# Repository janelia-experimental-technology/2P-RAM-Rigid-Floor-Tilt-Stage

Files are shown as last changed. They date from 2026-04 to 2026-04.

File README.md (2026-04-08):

### 2P-RAM Rigid Floor Tilt Stage

Various custom components have been designed for use with the 2P-RAM, including head plates and a motorized head positioner tilt stage. The original tilt stage is a motorized positioner intended for use with an air-suspended ball treadmill, which can be somewhat complex and expensive. An alternative is a rigid floor for the test subject with a single degree of freedom for adjustment. The design is compatible with the head plates offered in another repo from the Janelia Experimental Technology (jET) GitHub org.

Opportunity: Free to make for Non-Profit Research by downloading the design here. See included hardware license.

Rights and designs available for Commercial License. Janelia makes no endorsements or guarantees of licensee products.

For inquiries, please contact innovation@janelia.hhmi.org and reference this repository.

To cite the designs, please use DOI: https://doi.org/10.25378/janelia.31963896

Supersedes Flintbox ID: 2018-024

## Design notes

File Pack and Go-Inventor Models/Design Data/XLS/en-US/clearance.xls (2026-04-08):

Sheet: Ansi Unified Screw Threads
I | Sort Order -1
Fastener Type | Size | Shaft Diameters |  |  | Head Dimensions
 |  | Close | Normal | Loose | Diameter | Depth/Angle | Head Type
Flat Head Machine Screw (82) | #0 | 0.0635 | 0.07 | 0.073 | 0.119 | 82 | 2
Flat Head Machine Screw (82) | #1 | 0.076 | 0.081 | 0.089 | 0.146 | 82 | 2
Flat Head Machine Screw (82) | #2 | 0.089 | 0.096 | 0.1065 | 0.172 | 82 | 2
Flat Head Machine Screw (82) | #3 | 0.104 | 0.11 | 0.12 | 0.199 | 82 | 2
Flat Head Machine Screw (82) | #4 | 0.116 | 0.1285 | 0.136 | 0.225 | 82 | 2
Flat Head Machine Screw (82) | #5 | 0.1285 | 0.136 | 0.154 | 0.252 | 82 | 2
Flat Head Machine Screw (82) | #6 | 0.144 | 0.1495 | 0.1695 | 0.279 | 82 | 2
Flat Head Machine Screw (82) | #8 | 0.1695 | 0.177 | 0.1935 | 0.332 | 82 | 2
Flat Head Machine Screw (82) | #10 | 0.196 | 0.201 | 0.221 | 0.385 | 82 | 2
Flat Head Machine Screw (82) | #12 | 0.221 | 0.228 | 0.246 | 0.438 | 82 | 2
Flat Head Machine Screw (82) | 1/4 | 0.257 | 0.266 | 0.2812 | 0.507 | 82 | 2
Flat Head Machine Screw (82) | 5/16 | 0.323 | 0.332 | 0.3437 | 0.635 | 82 | 2
Flat Head Machine Screw (82) | 3/8 | 0.386 | 0.397 | 0.4062 | 0.762 | 82 | 2
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

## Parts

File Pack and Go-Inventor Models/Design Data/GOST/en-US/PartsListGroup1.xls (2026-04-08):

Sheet: Лист 1
Инв. № подл |  |  |  | Подп. и дата | Взам. инв. № | Инв. № дубл. |  |  | Подп. и дата
Формат | Зона | Поз. | Обозначение |  |  |  | Наименование |  |  |  |  |  | Кол. на исполнение
 |  |  |  |  |  |  |  |  |  |  |  | Лит.
 |  |  |  |  |  |  |  |  |  |  |  | Код
 |  |  |  |  |  |  |  | Изм. | Лист | № докум | Подпись |  | Дата
 |  |  |  |  |  |  |  | Разраб.
 |  |  |  |  |  |  |  | Пров.
 |  |  |  |  |  |  |  | Н.контр
 |  |  |  |  |  |  |  | Утв.
 |  |  |  |  |  |  |  |  |  |  |  |  |  | Копировал

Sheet: Лист 2
Инв. № подл |  |  |  | Подп. и дата | Взам. инв. № | Инв. № дубл. |  |  | Подп. и дата
Формат | Зона | Поз. | Обозначение |  |  |  | Наименование |  |  |  |  | Кол. на исполнение
 |  |  |  |  |  |  |  | Изм. | Лист | № докум. | Подп. | Дата
 |  |  |  |  |  |  |  |  |  |  |  |  | Копировал
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

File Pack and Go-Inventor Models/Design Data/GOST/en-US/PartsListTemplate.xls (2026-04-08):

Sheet: Лист 1
 | Формат | Зона |  | Поз. |  | Обозначение |  |  |  | Наименование |  |  |  | Кол. | Приме-чание
Подп. и дата
Инв. № дубл.
Взам. инв. №
Подп. и дата
 | Изм. |  | Лист |  | № докум |  | Подпись | Дата
Инв. № подл | Разраб. |  |  |  |  |  |  |  |  |  | Литера |  | Лист |  |  | Листов
 | Пров.
 | Н.контр
 | Утв.
 |  |  |  |  |  |  |  |  | Копировал |  |  | Формат А4

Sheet: Лист 2
 | Формат | Зона |  | Поз. |  | Обозначение |  |  |  | Наименование |  | Кол. | Приме-чание
Подп. и дата
Инв. № дубл.
Взам. инв. №
Подп. и дата
Инв. № подл
 | Изм. |  | Лист |  | № докум. |  | Подп. |  | Дата
 |  |  |  |  |  |  |  | Копировал |  |  | Формат А4
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

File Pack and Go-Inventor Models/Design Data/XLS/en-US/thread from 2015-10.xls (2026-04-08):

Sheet: Inch Tapping Threads
I Q X | Inch Tapping Threads |  | Sort Order - 5 |  | External |  |  |  |  |  |  | Internal
 |  |  |  |  |  | Major Dia |  | Pitch Dia |  | Minor Dia |  |  | Minor Dia |  | Pitch Dia |  | Major Dia |  | Tap Drill
Size | Size Suffix | Thread Designation | Custom Thread Designation | TPI | Class | Max | Min | Max | Min | Max | Min | Class | Min | Max | Min | Max | Min | Max | Basic
0.0600 |  | 0-48 | 0-48 | 48 | 2B | 0.0600 | 0.0540 | 0.0480 | 0.0435 | 0.0360 | 0.0330
0.0730 |  | 1-42 | 1-42 | 42 | 2B | 0.0750 | 0.0690 | 0.0620 | 0.0575 | 0.0490 | 0.0460
0.0860 |  | 2-32 | 2-32 | 32 | 2B | 0.0880 | 0.0820 | 0.0760 | 0.0710 | 0.0640 | 0.0600
0.0990 |  | 3-28 | 3-28 | 28 | 2B | 0.1010 | 0.0950 | 0.0880 | 0.0830 | 0.0750 | 0.0710
0.1120 |  | 4-24 | 4-24 | 24 | 2B | 0.1140 | 0.1080 | 0.1000 | 0.0950 | 0.0860 | 0.0820
0.1250 |  | 5-20 | 5-20 | 20 | 2B | 0.1300 | 0.1230 | 0.1120 | 0.1065 | 0.0940 | 0.0900
0.1380 |  | 6-20 | 6-20 | 20 | 2B | 0.1390 | 0.1320 | 0.1215 | 0.1155 | 0.1040 | 0.0990
0.1510 |  | 7-19 | 7-19 | 19 | 2B | 0.1540 | 0.1470 | 0.1345 | 0.1280 | 0.1150 | 0.1090
0.1640 |  | 8-18 | 8-18 | 18 | 2B | 0.1660 | 0.1590 | 0.1440 | 0.1375 | 0.1220 | 0.1160
0.1900 |  | 10-16 | 10-16 | 16 | 2B | 0.1890 | 0.1820 | 0.1650 | 0.1585 | 0.1410 | 0.1350
0.2160 |  | 12-14 | 12-14 | 14 | 2B | 0.2150 | 0.2080 | 0.1895 | 0.1825 | 0.1640 | 0.1570
0.2420 |  | 14-14 | 14-14 | 14 | 2B | 0.2410 | 0.2340 | 0.2130 | 0.2060 | 0.1850 | 0.1780
0.2500 |  | 1/4-14 | 1/4-14 | 14 | 2B | 0.2460 | 0.2370 | 0.2190 | 0.2110 | 0.1920 | 0.1850
0.3125 |  | 5/16-12 | 5/16-12 | 12 | 2B | 0.3150 | 0.3060 | 0.2795 | 0.2710 | 0.2440 | 0.2360
0.3750 |  | 3/8-12 | 3/8-12 | 12 | 2B | 0.3800 | 0.3710 | 0.3445 | 0.3350 | 0.3090 | 0.2990
0.4375 |  | 7/16-10 | 7/16-10 | 10 | 2B | 0.4400 | 0.4290 | 0.3995 | 0.3890 | 0.3590 | 0.3490
0.5000 |  | 1/2-10 | 1/2-10 | 10 | 2B | 0.5040 | 0.4930 | 0.4635 | 0.4530 | 0.4230 | 0.4130

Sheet: Metric Forming Screw Threads
M P X | Metric Forming Screw Threads |  | Sort Order - 6 |  | External |  |  |  |  |  |  | Internal
 |  |  |  |  |  | Major Dia |  | Pitch Dia |  | Minor Dia |  |  | Minor Dia |  | Pitch Dia |  | Major Dia |  | Tap Drill
Size | Size Suffix | Thread Designation | Custom Thread Designation | Pitch | Class | Max | Min | Max | Min | Max | Min | Class | Min | Max | Min | Max | Min | Max | Basic
1.5 |  | 1.5x0.5 | 1.5x0.5 | 0.5 | 6g | 1.520 | 1.380 | 1.215 | 1.110 | 0.910 | 0.840
1.5 |  | ST1.5x0.5 | ST1.5x0.5 | 0.5 | 6g | 1.520 | 1.380 | 1.215 | 1.110 | 0.910 | 0.840
1.9 |  | 1.9x0.6 | 1.9x0.6 | 0.6 | 6g | 1.900 | 1.760 | 1.570 | 1.465 | 1.240 | 1.170
1.9 |  | ST1.9x0.6 | ST1.9x0.6 | 0.6 | 6g | 1.900 | 1.760 | 1.570 | 1.465 | 1.240 | 1.170
2.2 |  | 2.2x0.8 | 2.2x0.8 | 0.8 | 6g | 2.240 | 2.100 | 1.935 | 1.810 | 1.630 | 1.520
2.2 |  | ST2.2x0.8 | ST2.2x0.8 | 0.8 | 6g | 2.240 | 2.100 | 1.935 | 1.810 | 1.630 | 1.520
2.6 |  | 2.6x0.9 | 2.6x0.9 | 0.9 | 6g | 2.570 | 2.430 | 2.235 | 2.115 | 1.900 | 1.800
2.6 |  | ST2.6x0.9 | ST2.6x0.9 | 0.9 | 6g | 2.570 | 2.430 | 2.235 | 2.115 | 1.900 | 1.800
2.9 |  | 2.9x1 | 2.9x1 | 1 | 6g | 2.900 | 2.760 | 2.540 | 2.420 | 2.180 | 2.080
2.9 |  | 2.9x1.1 | 2.9x1.1 | 1.1 | 6g | 2.900 | 2.760 | 2.540 | 2.420 | 2.180 | 2.080
2.9 |  | ST2.9x1.1 | ST2.9x1.1 | 1.1 | 6g | 2.900 | 2.760 | 2.540 | 2.420 | 2.180 | 2.080
2.9 |  | 2.9x1.3 | 2.9x1.3 | 1.3 | 6g | 2.900 | 2.720 | 2.540 | 2.355 | 1.890 | 1.700
2.9 |  | 2.9x1.4 | 2.9x1.4 | 1.4 | 6g | 2.900 | 2.720 | 2.340 | 2.175 | 1.780 | 1.630
3.3 |  | 3.3x1.3 | 3.3x1.3 | 1.3 | 6g | 3.300 | 3.120 | 2.795 | 2.665 | 2.290 | 2.210
3.3 |  | ST3.3x1.3 | ST3.3x1.3 | 1.3 | 6g | 3.300 | 3.120 | 2.795 | 2.665 | 2.290 | 2.210
3.5 |  | 3.5x1.3 | 3.5x1.3 | 1.3 | 6g | 3.530 | 3.350 | 3.085 | 2.930 | 2.640 | 2.510
3.5 |  | ST3.5x1.3 | ST3.5x1.3 | 1.3 | 6g | 3.530 | 3.350 | 3.085 | 2.930 | 2.640 | 2.510
3.5 |  | 3.5x1.6 | 3.5x1.6 | 1.6 | 6g | 3.530 | 3.350 | 2.920 | 2.755 | 2.310 | 2.160
3.5 |  | 3.5x3.2 | 3.5x3.2 | 3.2 | 6g | 3.530 | 3.310 | 2.800 | 2.600 | 2.070 | 1.890
3.9 |  | 3.9x1.3 | 3.9x1.3 | 1.3 | 6g | 3.910 | 3.730 | 3.415 | 3.250 | 2.920 | 2.770
3.9 |  | ST3.9x1.3 | ST3.9x1.3 | 1.3 | 6g | 3.910 | 3.730 | 3.415 | 3.250 | 2.920 | 2.770
3.9 |  | 3.9x1.6 | 3.9x1.6 | 1.6 | 6g | 3.910 | 3.730 | 3.300 | 3.135 | 2.690 | 2.540
3.9 |  | 3.9x3.2 | 3.9x3.2 | 3.2 | 6g | 3.910 | 3.690 | 3.180 | 2.980 | 2.450 | 2.270
4.2 |  | 4.2x1.4 | 4.2x1.4 | 1.4 | 6g | 4.220 | 4.040 | 3.660 | 3.495 | 3.100 | 2.950
4.2 |  | ST4.2x1.4 | ST4.2x1.4 | 1.4 | 6g | 4.220 | 4.040 | 3.660 | 3.495 | 3.100 | 2.950
4.2 |  | 4.2x1.6 | 4.2x1.6 | 1.6 | 6g | 4.220 | 4.040 | 3.610 | 3.445 | 3.000 | 2.850
4.2 |  | 4.2x3.2 | 4.2x3.2 | 3.2 | 6g | 4.220 | 4.000 | 3.380 | 3.180 | 2.540 | 2.360
4.8 |  | 4.8x1.6 | 4.8x1.6 | 1.6 | 6g | 4.800 | 4.620 | 4.190 | 4.025 | 3.580 | 3.430
4.8 |  | ST4.8x1.6 | ST4.8x1.6 | 1.6 | 6g | 4.800 | 4.620 | 4.190 | 4.025 | 3.580 | 3.430
4.8 |  | 4.8x1.8 | 4.8x1.8 | 1.8 | 6g | 4.800 | 4.620 | 4.065 | 3.885 | 3.330 | 3.150
4.8 |  | 4.8x3.2 | 4.8x3.2 | 3.2 | 6g | 4.800 | 4.580 | 3.960 | 3.760 | 3.120 | 2.940
5.5 |  | 5.5x1.8 | 5.5x1.8 | 1.8 | 6g | 5.460 | 5.280 | 4.815 | 4.635 | 4.170 | 3.990
5.5 |  | ST5.5x1.8 | ST5.5x1.8 | 1.8 | 6g | 5.460 | 5.280 | 4.815 | 4.635 | 4.170 | 3.990
6.3 |  | 6.3x1.8 | 6.3x1.8 | 1.8 | 6g | 6.250 | 6.030 | 5.565 | 5.365 | 4.880 | 4.700
6.3 |  | ST6.3x1.8 | ST6.3x1.8 | 1.8 | 6g | 6.250 | 6.030 | 5.565 | 5.365 | 4.880 | 4.700
8.0 |  | 8x2.1 | 8x2.1 | 2.1 | 6g | 8.000 | 7.780 | 7.100 | 6.885 | 6.200 | 5.990
8.0 |  | ST8x2.1 | ST8x2.1 | 2.1 | 6g | 8.000 | 7.780 | 7.100 | 6.885 | 6.200 | 5.990
9.5 |  | 9.5x2.1 | 9.5x2.1 | 2.1 | 6g | 9.650 | 9.430 | 8.750 | 8.510 | 7.850 | 7.590
9.5 |  | ST9.5x2.1 | ST9.5x2.1 | 2.1 | 6g | 9.650 | 9.430 | 8.750 | 8.510 | 7.850 | 7.590

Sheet: ISO Pipe Threads
M Q | ISO Pipe Threads |  | Sort Order - 9 |  | External |  |  |  |  |  |  | Internal
 |  |  |  |  |  | Major Dia |  | Pitch Dia |  | Minor Dia |  |  | Minor Dia |  | Pitch Dia |  | Major Dia |  | Tap Drill | Thread Depth | Thread Runouts
Size | Size Suffix | Thread Designation | Custom Thread Designation | TPI | Class | Max | Min | Max | Min | Max | Min | Class | Min | Max | Min | Max | Min | Max | Basic
7.723 |  | G7.723x0.907 | G 1/16 | 28 | A | 7.723 | 7.509 | 7.142 | 7.035 | 6.561 |  |  | 6.561 | 6.834 | 7.142 | 7.249 | 7.723 |  | 1.5875 | 15.446 | 4.5000
7.723 |  | G7.723x0.907 | G 1/16 | 28 | B | 7.723 | 7.509 | 7.142 | 6.928 | 6.561
9.728 |  | G9.728x0.907 | G 1/8 | 28 | A | 9.728 | 9.514 | 9.147 | 9.040 | 8.566 |  |  | 8.566 | 8.848 | 9.147 | 9.254 | 9.728 |  | 3.1750 | 19.456 | 4.5000
9.728 |  | G9.728x0.907 | G 1/8 | 28 | B | 9.728 | 9.514 | 9.147 | 8.933 | 8.566
13.157 |  | G13.157x1.337 | G 1/4 | 19 | A | 13.157 | 12.907 | 12.301 | 12.176 | 11.445 |  |  | 11.445 | 11.89 | 12.301 | 12.426 | 13.157 |  | 6.3500 | 26.314 | 6.5000
13.157 |  | G13.157x1.337 | G 1/4 | 19 | B | 13.157 | 12.907 | 12.301 | 12.051 | 11.445
16.662 |  | G16.662x1.337 | G 3/8 | 19 | A | 16.662 | 16.412 | 15.806 | 15.681 | 14.950 |  |  | 14.95 | 15.395 | 15.806 | 15.931 | 16.662 |  | 9.5250 | 33.324 | 6.5000
16.662 |  | G16.662x1.337 | G 3/8 | 19 | B | 16.662 | 16.412 | 15.806 | 15.556 | 14.950
20.955 |  | G20.955x1.814 | G 1/2 | 14 | A | 20.955 | 20.671 | 19.793 | 19.651 | 18.631 |  |  | 18.631 | 19.172 | 19.793 | 19.935 | 20.955 |  | 12.7000 | 41.910 | 8.5000
20.955 |  | G20.955x1.814 | G 1/2 | 14 | B | 20.955 | 20.671 | 19.793 | 19.509 | 18.631
22.911 |  | G22.911x1.814 | G 5/8 | 14 | A | 22.911 | 22.627 | 21.749 | 21.607 | 20.587 |  |  | 20.587 | 21.128 | 21.749 | 21.891 | 22.911 |  |  | 45.822 | 8.5000
22.911 |  | G22.911x1.814 | G 5/8 | 14 | B | 22.911 | 22.627 | 21.749 | 21.465 | 20.587
26.441 |  | G26.441x1.814 | G 3/4 | 14 | A | 26.441 | 26.157 | 25.279 | 25.137 | 24.117 |  |  | 24.117 | 24.658 | 25.279 | 25.421 | 26.441 |  | 15.8750 | 52.882 | 8.5000
26.441 |  | G26.441x1.814 | G 3/4 | 14 | B | 26.441 | 26.157 | 25.279 | 24.995 | 24.117
30.201 |  | G30.201x1.814 | G 7/8 | 14 | A | 30.201 | 29.917 | 29.039 | 28.897 | 27.877 |  |  | 27.877 | 28.418 | 29.039 | 29.181 | 30.201 |  | 22.2250 | 60.402 | 8.5000
30.201 |  | G30.201x1.814 | G 7/8 | 14 | B | 30.201 | 29.917 | 29.039 | 28.755 | 27.877
33.249 |  | G33.249x2.309 | G 1 | 11 | A | 33.249 | 32.889 | 31.770 | 31.590 | 30.291 |  |  | 30.291 | 30.931 | 31.77 | 31.95 | 33.249 |  | 25.4000 | 66.498 | 10.0000
33.249 |  | G33.249x2.309 | G 1 | 11 | B | 33.249 | 32.889 | 31.770 | 31.410 | 30.291
37.897 |  | G37.897x2.309 | G 1 1/8 | 11 | A | 37.897 | 37.537 | 36.418 | 36.238 | 34.939 |  |  | 34.939 | 35.579 | 36.418 | 36.598 | 37.897 |  | 28.5750 | 75.794 | 10.0000
37.897 |  | G37.897x2.309 | G 1 1/8 | 11 | B | 37.897 | 37.537 | 36.418 | 36.058 | 34.939
41.910 |  | G41.91x2.309 | G 1 1/4 | 11 | A | 41.910 | 41.550 | 40.431 | 40.251 | 38.952 |  |  | 38.952 | 39.592 | 40.431 | 40.611 | 41.910 |  | 31.7500 | 83.820 | 10.0000
41.910 |  | G41.91x2.309 | G 1 1/4 | 11 | B | 41.910 | 41.550 | 40.431 | 40.071 | 38.952
47.803 |  | G47.803x2.309 | G 1 1/2 | 11 | A | 47.803 | 47.443 | 46.324 | 46.144 | 44.845 |  |  | 44.845 | 45.485 | 46.324 | 46.504 | 47.803 |  | 38.1000 | 95.606 | 10.0000
47.803 |  | G47.803x2.309 | G 1 1/2 | 11 | B | 47.803 | 47.443 | 46.324 | 45.964 | 44.845
53.746 |  | G53.746x2.309 | G 1 3/4 | 11 | A | 53.746 | 53.386 | 52.267 | 52.087 | 50.788 |  |  | 50.788 | 51.428 | 52.267 | 52.447 | 53.746 |  | 44.4500 | 107.492 | 10.0000
53.746 |  | G53.746x2.309 | G 1 3/4 | 11 | B | 53.746 | 53.386 | 52.267 | 51.907 | 50.788
59.614 |  | G59.614x2.309 | G 2 | 11 | A | 59.614 | 59.254 | 58.135 | 57.955 | 56.656 |  |  | 56.656 | 57.296 | 58.135 | 58.315 | 59.614 |  | 50.8000 | 119.228 | 10.0000
59.614 |  | G59.614x2.309 | G 2 | 11 | B | 59.614 | 59.254 | 58.135 | 57.775 | 56.656
65.710 |  | G65.71x2.309 | G 2 1/4 | 11 | A | 65.710 | 65.276 | 64.231 | 64.014 | 62.752 |  |  | 62.752 | 63.392 | 64.231 | 64.448 | 65.710 |  | 57.1500 | 131.420 | 10.0000
65.710 |  | G65.71x2.309 | G 2 1/4 | 11 | B | 65.710 | 65.276 | 64.231 | 63.797 | 62.752
75.184 |  | G75.184x2.309 | G 2 1/2 | 11 | A | 75.184 | 74.750 | 73.705 | 73.488 | 72.226 |  |  | 72.226 | 72.866 | 73.705 | 73.922 | 75.184 |  |  | 150.368 | 10.0000
75.184 |  | G75.184x2.309 | G 2 1/2 | 11 | B | 75.184 | 74.750 | 73.705 | 73.271 | 72.226
81.534 |  | G81.534x2.309 | G 2 3/4 | 11 | A | 81.534 | 81.100 | 80.055 | 79.838 | 78.576 |  |  | 78.576 | 79.216 | 80.055 | 80.272 | 81.534 |  | 69.8500 | 163.068 | 10.0000
81.534 |  | G81.534x2.309 | G 2 3/4 | 11 | B | 81.534 | 81.100 | 80.055 | 79.621 | 78.576
87.884 |  | G87.884x2.309 | G 3 | 11 | A | 87.884 | 87.450 | 86.405 | 86.188 | 84.926 |  |  | 84.926 | 85.566 | 86.405 | 86.622 | 87.884 |  | 76.2000 | 175.768 | 10.0000
87.884 |  | G87.884x2.309 | G 3 | 11 | B | 87.884 | 87.450 | 86.405 | 85.971 | 84.926
100.330 |  | G100.33x2.309 | G 3 1/2 | 11 | A | 100.330 | 99.896 | 98.851 | 98.634 | 97.372 |  |  | 97.372 | 98.012 | 98.851 | 99.068 | 100.330 |  | 88.9000 | 200.660 | 10.0000
100.330 |  | G100.33x2.309 | G 3 1/2 | 11 | B | 100.330 | 99.896 | 98.851 | 98.417 | 97.372
113.030 |  | G113.03x2.309 | G 4 | 11 | A | 113.030 | 112.596 | 111.551 | 111.334 | 110.072 |  |  | 110.072 | 110.712 | 111.551 | 111.768 | 113.030 |  | 101.6000 | 226.060 | 10.0000
113.030 |  | G113.03x2.309 | G 4 | 11 | B | 113.030 | 112.596 | 111.551 | 111.117 | 110.072
125.730 |  | G125.73x2.309 | G 4 1/2 | 11 | A | 125.730 | 125.296 | 124.251 | 124.034 | 122.772 |  |  | 122.772 | 123.412 | 124.251 | 124.468 | 125.730 |  | 114.3000 | 251.460 | 10.0000
125.730 |  | G125.73x2.309 | G 4 1/2 | 11 | B | 125.730 | 125.296 | 124.251 | 123.817 | 122.772
138.430 |  | G138.43x2.309 | G 5 | 11 | A | 138.430 | 137.996 | 136.951 | 136.734 | 135.472 |  |  | 135.472 | 136.112 | 136.951 | 137.168 | 138.430 |  | 127.0000 | 276.860 | 10.0000
138.430 |  | G138.43x2.309 | G 5 | 11 | B | 138.430 | 137.996 | 136.951 | 136.517 | 135.472
151.130 |  | G151.13x2.309 | G 5 1/2 | 11 | A | 151.130 | 150.696 | 149.651 | 149.434 | 148.172 |  |  | 148.172 | 148.812 | 149.651 | 149.868 | 151.130 |  | 139.7000 | 302.260 | 10.0000
151.130 |  | G151.13x2.309 | G 5 1/2 | 11 | B | 151.130 | 150.696 | 149.651 | 149.217 | 148.172
163.830 |  | G163.83x2.309 | G 6 | 11 | A | 163.830 | 163.396 | 162.351 | 162.134 | 160.872 |  |  | 160.872 | 161.512 | 162.351 | 162.568 | 163.830 |  | 152.4000 | 327.660 | 10.0000
163.830 |  | G163.83x2.309 | G 6 | 11 | B | 163.830 | 163.396 | 162.351 | 161.917 | 160.872

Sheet: JIS Pipe Threads
M Q | JIS Pipe Threads |  | Sort Order -12 |  | External |  |  |  |  |  |  | Internal
 |  |  |  |  |  | Major Dia |  | Pitch Dia |  | Minor Dia |  |  | Minor Dia |  | Pitch Dia |  | Major Dia |  | Tap Drill | Thread Depth | Thread Runouts
Size | Size Suffix | Thread Designation | Custom Thread Designation | TPI | Class | Max | Min | Max | Min | Max | Min | Class | Min | Max | Min | Max | Min | Max | Basic |  | Basic
7.723 |  | G7.723x0.907 | G 1/16 | 28 | A | 7.723 | 7.509 | 7.142 | 7.035 | 6.561 |  |  | 6.561 | 6.834 | 7.142 | 7.249 | 7.723 |  | 1.5875 | 15.446 | 4.5000
7.723 |  | G7.723x0.907 | G 1/16 | 28 | B | 7.723 | 7.509 | 7.142 | 6.928 | 6.561
9.728 |  | G9.728x0.907 | G 1/8 | 28 | A | 9.728 | 9.514 | 9.147 | 9.040 | 8.566 |  |  | 8.566 | 8.848 | 9.147 | 9.254 | 9.728 |  | 3.1750 | 19.456 | 4.5000
9.728 |  | G9.728x0.907 | G 1/8 | 28 | B | 9.728 | 9.514 | 9.147 | 8.933 | 8.566
13.157 |  | G13.157x1.337 | G 1/4 | 19 | A | 13.157 | 12.907 | 12.301 | 12.176 | 11.445 |  |  | 11.445 | 11.89 | 12.301 | 12.426 | 13.157 |  | 6.3500 | 26.314 | 6.5000
13.157 |  | G13.157x1.337 | G 1/4 | 19 | B | 13.157 | 12.907 | 12.301 | 12.051 | 11.445
16.662 |  | G16.662x1.337 | G 3/8 | 19 | A | 16.662 | 16.412 | 15.806 | 15.681 | 14.950 |  |  | 14.95 | 15.395 | 15.806 | 15.931 | 16.662 |  | 9.5250 | 33.324 | 6.5000
16.662 |  | G16.662x1.337 | G 3/8 | 19 | B | 16.662 | 16.412 | 15.806 | 15.556 | 14.950
20.955 |  | G20.955x1.814 | G 1/2 | 14 | A | 20.955 | 20.671 | 19.793 | 19.651 | 18.631 |  |  | 18.631 | 19.172 | 19.793 | 19.935 | 20.955 |  | 12.7000 | 41.910 | 8.5000
20.955 |  | G20.955x1.814 | G 1/2 | 14 | B | 20.955 | 20.671 | 19.793 | 19.509 | 18.631
22.911 |  | G22.911x1.814 | G 5/8 | 14 | A | 22.911 | 22.627 | 21.749 | 21.607 | 20.587 |  |  | 20.587 | 21.128 | 21.749 | 21.891 | 22.911 |  |  | 45.822 | 8.5000
22.911 |  | G22.911x1.814 | G 5/8 | 14 | B | 22.911 | 22.627 | 21.749 | 21.465 | 20.587
26.441 |  | G26.441x1.814 | G 3/4 | 14 | A | 26.441 | 26.157 | 25.279 | 25.137 | 24.117 |  |  | 24.117 | 24.658 | 25.279 | 25.421 | 26.441 |  | 15.8750 | 52.882 | 8.5000
26.441 |  | G26.441x1.814 | G 3/4 | 14 | B | 26.441 | 26.157 | 25.279 | 24.995 | 24.117
30.201 |  | G30.201x1.814 | G 7/8 | 14 | A | 30.201 | 29.917 | 29.039 | 28.897 | 27.877 |  |  | 27.877 | 28.418 | 29.039 | 29.181 | 30.201 |  | 22.2250 | 60.402 | 8.8000
30.201 |  | G30.201x1.814 | G 7/8 | 14 | B | 30.201 | 29.917 | 29.039 | 28.755 | 27.877
33.249 |  | G33.249x2.309 | G 1 | 11 | A | 33.249 | 32.889 | 31.770 | 31.590 | 30.291 |  |  | 30.291 | 30.931 | 31.77 | 31.95 | 33.249 |  | 25.4000 | 66.498 | 10.0000
33.249 |  | G33.249x2.309 | G 1 | 11 | B | 33.249 | 32.889 | 31.770 | 31.410 | 30.291
37.897 |  | G37.897x2.309 | G 1 1/8 | 11 | A | 37.897 | 37.537 | 36.418 | 36.238 | 34.939 |  |  | 34.939 | 35.579 | 36.418 | 36.598 | 37.897 |  | 28.5750 | 75.794 | 10.0000
37.897 |  | G37.897x2.309 | G 1 1/8 | 11 | B | 37.897 | 37.537 | 36.418 | 36.058 | 34.939
41.910 |  | G41.91x2.309 | G 1 1/4 | 11 | A | 41.910 | 41.550 | 40.431 | 40.251 | 38.952 |  |  | 38.952 | 39.592 | 40.431 | 40.611 | 41.910 |  | 31.7500 | 83.820 | 10.0000
41.910 |  | G41.91x2.309 | G 1 1/4 | 11 | B | 41.910 | 41.550 | 40.431 | 40.071 | 38.952
47.803 |  | G47.803x2.309 | G 1 1/2 | 11 | A | 47.803 | 47.443 | 46.324 | 46.144 | 44.845 |  |  | 44.845 | 45.485 | 46.324 | 46.504 | 47.803 |  | 38.1000 | 95.606 | 10.0000
47.803 |  | G47.803x2.309 | G 1 1/2 | 11 | B | 47.803 | 47.443 | 46.324 | 45.964 | 44.845
53.746 |  | G53.746x2.309 | G 1 3/4 | 11 | A | 53.746 | 53.386 | 52.267 | 52.087 | 50.788 |  |  | 50.788 | 51.428 | 52.267 | 52.447 | 53.746 |  | 44.4500 | 107.492 | 10.0000
53.746 |  | G53.746x2.309 | G 1 3/4 | 11 | B | 53.746 | 53.386 | 52.267 | 51.907 | 50.788
59.614 |  | G59.614x2.309 | G 2 | 11 | A | 59.614 | 59.254 | 58.135 | 57.955 | 56.656 |  |  | 56.656 | 57.296 | 58.135 | 58.315 | 59.614 |  | 50.8000 | 119.228 | 10.0000
59.614 |  | G59.614x2.309 | G 2 | 11 | B | 59.614 | 59.254 | 58.135 | 57.775 | 56.656
65.710 |  | G65.71x2.309 | G 2 1/4 | 11 | A | 65.710 | 65.276 | 64.231 | 64.014 | 62.752 |  |  | 62.752 | 63.392 | 64.231 | 64.448 | 65.710 |  | 57.1500 | 131.420 | 10.0000
65.710 |  | G65.71x2.309 | G 2 1/4 | 11 | B | 65.710 | 65.276 | 64.231 | 63.797 | 62.752
75.184 |  | G75.184x2.309 | G 2 1/2 | 11 | A | 75.184 | 74.750 | 73.705 | 73.488 | 72.226 |  |  | 72.226 | 72.866 | 73.705 | 73.922 | 75.184 |  |  | 150.368 | 10.0000
75.184 |  | G75.184x2.309 | G 2 1/2 | 11 | B | 75.184 | 74.750 | 73.705 | 73.271 | 72.226
81.534 |  | G81.534x2.309 | G 2 3/4 | 11 | A | 81.534 | 81.100 | 80.055 | 79.838 | 78.576 |  |  | 78.576 | 79.216 | 80.055 | 80.272 | 81.534 |  | 69.8500 | 163.068 | 10.0000
81.534 |  | G81.534x2.309 | G 2 3/4 | 11 | B | 81.534 | 81.100 | 80.055 | 79.621 | 78.576
87.884 |  | G87.884x2.309 | G 3 | 11 | A | 87.884 | 87.450 | 86.405 | 86.188 | 84.926 |  |  | 84.926 | 85.566 | 86.405 | 86.622 | 87.884 |  | 76.2000 | 175.768 | 10.0000
87.884 |  | G87.884x2.309 | G 3 | 11 | B | 87.884 | 87.450 | 86.405 | 85.971 | 84.926
100.330 |  | G100.33x2.309 | G 3 1/2 | 11 | A | 100.330 | 99.896 | 98.851 | 98.634 | 97.372 |  |  | 97.372 | 98.012 | 98.851 | 99.068 | 100.330 |  | 88.9000 | 200.660 | 10.0000
100.330 |  | G100.33x2.309 | G 3 1/2 | 11 | B | 100.330 | 99.896 | 98.851 | 98.417 | 97.372
113.030 |  | G113.03x2.309 | G 4 | 11 | A | 113.030 | 112.596 | 111.551 | 111.334 | 110.072 |  |  | 110.072 | 110.712 | 111.551 | 111.768 | 113.030 |  | 101.6000 | 226.060 | 10.0000
113.030 |  | G113.03x2.309 | G 4 | 11 | B | 113.030 | 112.596 | 111.551 | 111.117 | 110.072
125.730 |  | G125.73x2.309 | G 4 1/2 | 11 | A | 125.730 | 125.296 | 124.251 | 124.034 | 122.772 |  |  | 122.772 | 123.412 | 124.251 | 124.468 | 125.730 |  | 114.3000 | 251.460 | 10.0000
125.730 |  | G125.73x2.309 | G 4 1/2 | 11 | B | 125.730 | 125.296 | 124.251 | 123.817 | 122.772
138.430 |  | G138.43x2.309 | G 5 | 11 | A | 138.430 | 137.996 | 136.951 | 136.734 | 135.472 |  |  | 135.472 | 136.112 | 136.951 | 137.168 | 138.430 |  | 127.0000 | 276.860 | 10.0000
138.430 |  | G138.43x2.309 | G 5 | 11 | B | 138.430 | 137.996 | 136.951 | 136.517 | 135.472
151.130 |  | G151.13x2.309 | G 5 1/2 | 11 | A | 151.130 | 150.696 | 149.651 | 149.434 | 148.172 |  |  | 148.172 | 148.812 | 149.651 | 149.868 | 151.130 |  | 139.7000 | 302.260 | 10.0000
151.130 |  | G151.13x2.309 | G 5 1/2 | 11 | B | 151.130 | 150.696 | 149.651 | 149.217 | 148.172
163.830 |  | G163.83x2.309 | G 6 | 11 | A | 163.830 | 163.396 | 162.351 | 162.134 | 160.872 |  |  | 160.872 | 161.512 | 162.351 | 162.568 | 163.830 |  | 152.4000 | 327.660 | 10.0000
163.830 |  | G163.83x2.309 | G 6 | 11 | B | 163.830 | 163.396 | 162.351 | 161.917 | 160.872

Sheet: DIN Pipe Threads
M Q | DIN Pipe Threads |  | Sort Order - 18 |  | External |  |  |  |  |  |  | Internal
 |  |  |  |  |  | Major Dia |  | Pitch Dia |  | Minor Dia |  |  | Minor Dia |  | Pitch Dia |  | Major Dia |  | Tap Drill | Thread Depth | Thread Runouts
Size | Size Suffix | Thread Designation | Custom Thread Designation | TPI | Class | Max | Min | Max | Min | Max | Min | Class | Min | Max | Min | Max | Min | Max | Basic
7.723 |  | G7.723x0.907 | G 1/16 | 28 | A | 7.723 | 7.509 | 7.142 | 7.035 | 6.561 |  |  | 6.561 | 6.834 | 7.142 | 7.249 | 7.723 |  | 1.5875 | 15.446 | 4.5000
7.723 |  | G7.723x0.907 | G 1/16 | 28 | B | 7.723 | 7.509 | 7.142 | 6.928 | 6.561
9.728 |  | G9.728x0.907 | G 1/8 | 28 | A | 9.728 | 9.514 | 9.147 | 9.040 | 8.566 |  |  | 8.566 | 8.848 | 9.147 | 9.254 | 9.728 |  | 3.1750 | 19.456 | 4.5000
9.728 |  | G9.728x0.907 | G 1/8 | 28 | B | 9.728 | 9.514 | 9.147 | 8.933 | 8.566
13.157 |  | G13.157x1.337 | G 1/4 | 19 | A | 13.157 | 12.907 | 12.301 | 12.176 | 11.445 |  |  | 11.445 | 11.89 | 12.301 | 12.426 | 13.157 |  | 6.3500 | 26.314 | 6.5000
13.157 |  | G13.157x1.337 | G 1/4 | 19 | B | 13.157 | 12.907 | 12.301 | 12.051 | 11.445
16.662 |  | G16.662x1.337 | G 3/8 | 19 | A | 16.662 | 16.412 | 15.806 | 15.681 | 14.950 |  |  | 14.95 | 15.395 | 15.806 | 15.931 | 16.662 |  | 9.5250 | 33.324 | 6.5000
16.662 |  | G16.662x1.337 | G 3/8 | 19 | B | 16.662 | 16.412 | 15.806 | 15.556 | 14.950
20.955 |  | G20.955x1.814 | G 1/2 | 14 | A | 20.955 | 20.671 | 19.793 | 19.651 | 18.631 |  |  | 18.631 | 19.172 | 19.793 | 19.935 | 20.955 |  | 12.7000 | 41.910 | 8.5000
20.955 |  | G20.955x1.814 | G 1/2 | 14 | B | 20.955 | 20.671 | 19.793 | 19.509 | 18.631
22.911 |  | G22.911x1.814 | G 5/8 | 14 | A | 22.911 | 22.627 | 21.749 | 21.607 | 20.587 |  |  | 20.587 | 21.128 | 21.749 | 21.891 | 22.911 |  |  | 45.822 | 8.5000
22.911 |  | G22.911x1.814 | G 5/8 | 14 | B | 22.911 | 22.627 | 21.749 | 21.465 | 20.587
26.441 |  | G26.441x1.814 | G 3/4 | 14 | A | 26.441 | 26.157 | 25.279 | 25.137 | 24.117 |  |  | 24.117 | 24.658 | 25.279 | 25.421 | 26.441 |  | 15.8750 | 52.882 | 8.5000
26.441 |  | G26.441x1.814 | G 3/4 | 14 | B | 26.441 | 26.157 | 25.279 | 24.995 | 24.117
30.201 |  | G30.201x1.814 | G 7/8 | 14 | A | 30.201 | 29.917 | 29.039 | 28.897 | 27.877 |  |  | 27.877 | 28.418 | 29.039 | 29.181 | 30.201 |  | 22.2250 | 60.402 | 8.5000
30.201 |  | G30.201x1.814 | G 7/8 | 14 | B | 30.201 | 29.917 | 29.039 | 28.755 | 27.877
33.249 |  | G33.249x2.309 | G 1 | 11 | A | 33.249 | 32.889 | 31.770 | 31.590 | 30.291 |  |  | 30.291 | 30.931 | 31.77 | 31.95 | 33.249 |  | 25.4000 | 66.498 | 10.5000
33.249 |  | G33.249x2.309 | G 1 | 11 | B | 33.249 | 32.889 | 31.770 | 31.410 | 30.291
37.897 |  | G37.897x2.309 | G 1 1/8 | 11 | A | 37.897 | 37.537 | 36.418 | 36.238 | 34.939 |  |  | 34.939 | 35.579 | 36.418 | 36.598 | 37.897 |  | 28.5750 | 75.794 | 10.5000
37.897 |  | G37.897x2.309 | G 1 1/8 | 11 | B | 37.897 | 37.537 | 36.418 | 36.058 | 34.939
41.910 |  | G41.91x2.309 | G 1 1/4 | 11 | A | 41.910 | 41.550 | 40.431 | 40.251 | 38.952 |  |  | 38.952 | 39.592 | 40.431 | 40.611 | 41.910 |  | 31.7500 | 83.820 | 10.5000
41.910 |  | G41.91x2.309 | G 1 1/4 | 11 | B | 41.910 | 41.550 | 40.431 | 40.071 | 38.952
47.803 |  | G47.803x2.309 | G 1 1/2 | 11 | A | 47.803 | 47.443 | 46.324 | 46.144 | 44.845 |  |  | 44.845 | 45.485 | 46.324 | 46.504 | 47.803 |  | 38.1000 | 95.606 | 10.5000
47.803 |  | G47.803x2.309 | G 1 1/2 | 11 | B | 47.803 | 47.443 | 46.324 | 45.964 | 44.845
53.746 |  | G53.746x2.309 | G 1 3/4 | 11 | A | 53.746 | 53.386 | 52.267 | 52.087 | 50.788 |  |  | 50.788 | 51.428 | 52.267 | 52.447 | 53.746 |  | 44.4500 | 107.492 | 10.5000
53.746 |  | G53.746x2.309 | G 1 3/4 | 11 | B | 53.746 | 53.386 | 52.267 | 51.907 | 50.788
59.614 |  | G59.614x2.309 | G 2 | 11 | A | 59.614 | 59.254 | 58.135 | 57.955 | 56.656 |  |  | 56.656 | 57.296 | 58.135 | 58.315 | 59.614 |  | 50.8000 | 119.228 | 10.5000
59.614 |  | G59.614x2.309 | G 2 | 11 | B | 59.614 | 59.254 | 58.135 | 57.775 | 56.656
65.710 |  | G65.71x2.309 | G 2 1/4 | 11 | A | 65.710 | 65.276 | 64.231 | 64.014 | 62.752 |  |  | 62.752 | 63.392 | 64.231 | 64.448 | 65.710 |  | 57.1500 | 131.420 | 10.5000
65.710 |  | G65.71x2.309 | G 2 1/4 | 11 | B | 65.710 | 65.276 | 64.231 | 63.797 | 62.752
75.184 |  | G75.184x2.309 | G 2 1/2 | 11 | A | 75.184 | 74.750 | 73.705 | 73.488 | 72.226 |  |  | 72.226 | 72.866 | 73.705 | 73.922 | 75.184 |  |  | 150.368 | 10.5000
75.184 |  | G75.184x2.309 | G 2 1/2 | 11 | B | 75.184 | 74.750 | 73.705 | 73.271 | 72.226
81.534 |  | G81.534x2.309 | G 2 3/4 | 11 | A | 81.534 | 81.100 | 80.055 | 79.838 | 78.576 |  |  | 78.576 | 79.216 | 80.055 | 80.272 | 81.534 |  | 69.8500 | 163.068 | 10.5000
81.534 |  | G81.534x2.309 | G 2 3/4 | 11 | B | 81.534 | 81.100 | 80.055 | 79.621 | 78.576
87.884 |  | G87.884x2.309 | G 3 | 11 | A | 87.884 | 87.450 | 86.405 | 86.188 | 84.926 |  |  | 84.926 | 85.566 | 86.405 | 86.622 | 87.884 |  | 76.2000 | 175.768 | 10.5000
87.884 |  | G87.884x2.309 | G 3 | 11 | B | 87.884 | 87.450 | 86.405 | 85.971 | 84.926
100.330 |  | G100.33x2.309 | G 3 1/2 | 11 | A | 100.330 | 99.896 | 98.851 | 98.634 | 97.372 |  |  | 97.372 | 98.012 | 98.851 | 99.068 | 100.330 |  | 88.9000 | 200.660 | 10.5000
100.330 |  | G100.33x2.309 | G 3 1/2 | 11 | B | 100.330 | 99.896 | 98.851 | 98.417 | 97.372
113.030 |  | G113.03x2.309 | G 4 | 11 | A | 113.030 | 112.596 | 111.551 | 111.334 | 110.072 |  |  | 110.072 | 110.712 | 111.551 | 111.768 | 113.030 |  | 101.6000 | 226.060 | 10.5000
113.030 |  | G113.03x2.309 | G 4 | 11 | B | 113.030 | 112.596 | 111.551 | 111.117 | 110.072
125.730 |  | G125.73x2.309 | G 4 1/2 | 11 | A | 125.730 | 125.296 | 124.251 | 124.034 | 122.772 |  |  | 122.772 | 123.412 | 124.251 | 124.468 | 125.730 |  | 114.3000 | 251.460 | 10.5000
125.730 |  | G125.73x2.309 | G 4 1/2 | 11 | B | 125.730 | 125.296 | 124.251 | 123.817 | 122.772
138.430 |  | G138.43x2.309 | G 5 | 11 | A | 138.430 | 137.996 | 136.951 | 136.734 | 135.472 |  |  | 135.472 | 136.112 | 136.951 | 137.168 | 138.430 |  | 127.0000 | 276.860 | 10.5000
138.430 |  | G138.43x2.309 | G 5 | 11 | B | 138.430 | 137.996 | 136.951 | 136.517 | 135.472
151.130 |  | G151.13x2.309 | G 5 1/2 | 11 | A | 151.130 | 150.696 | 149.651 | 149.434 | 148.172 |  |  | 148.172 | 148.812 | 149.651 | 149.868 | 151.130 |  | 139.7000 | 302.260 | 10.5000
151.130 |  | G151.13x2.309 | G 5 1/2 | 11 | B | 151.130 | 150.696 | 149.651 | 149.217 | 148.172
163.830 |  | G163.83x2.309 | G 6 | 11 | A | 163.830 | 163.396 | 162.351 | 162.134 | 160.872 |  |  | 160.872 | 161.512 | 162.351 | 162.568 | 163.830 |  | 152.4000 | 327.660 | 10.5000
163.830 |  | G163.83x2.309 | G 6 | 11 | B | 163.830 | 163.396 | 162.351 | 161.917 | 160.872

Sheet: BSP Pipe Threads
M Q | BSP Pipe Threads |  | Sort Order - 19 |  | External |  |  |  |  |  |  | Internal
 |  |  |  |  |  | Major Dia |  | Pitch Dia |  | Minor Dia |  |  | Minor Dia |  | Pitch Dia |  | Major Dia |  | Tap Drill | Thread Depth | Thread Runouts
Size | Size Suffix | Thread Designation | Custom Thread Designation | TPI | Class | Max | Min | Max | Min | Max | Min | Class | Min | Max | Min | Max | Min | Max | Basic |  | Basic
1/16 |  | G 1/16-28 | G 1/16-28 | 28 | A | 7.723 | 7.509 | 7.142 | 7.035 | 6.561 |  |  | 6.561 | 6.834 | 7.142 | 7.249 | 7.723 |  | 6.6000 | 15.4460 | 4.5000
1/16 |  | G 1/16-28 | G 1/16-28 | 28 | B | 7.723 | 7.509 | 7.142 | 7.035 | 6.561
1/8 |  | G 1/8-28 | G 1/8-28 | 28 | A | 9.728 | 9.514 | 9.147 | 9.040 | 8.566 |  |  | 8.566 | 8.848 | 9.147 | 9.254 | 9.728 |  | 8.7300 | 19.4560 | 4.5000
1/8 |  | G 1/8-28 | G 1/8-28 | 28 | B | 9.728 | 9.514 | 9.147 | 9.040 | 8.566
1/4 |  | G 1/4-19 | G 1/4-19 | 19 | A | 13.157 | 12.907 | 12.301 | 12.176 | 11.445 |  |  | 11.445 | 11.89 | 12.301 | 12.426 | 13.157 |  | 11.8000 | 26.3140 | 6.5000
1/4 |  | G 1/4-19 | G 1/4-19 | 19 | B | 13.157 | 12.907 | 12.301 | 12.176 | 11.445
3/8 |  | G 3/8-19 | G 3/8-19 | 19 | A | 16.662 | 16.412 | 15.806 | 15.681 | 14.950 |  |  | 14.95 | 15.395 | 15.806 | 15.931 | 16.662 |  | 15.2500 | 33.3240 | 6.5000
3/8 |  | G 3/8-19 | G 3/8-19 | 19 | B | 16.662 | 16.412 | 15.806 | 15.681 | 14.950
1/2 |  | G 1/2-14 | G 1/2-14 | 14 | A | 20.955 | 20.671 | 19.793 | 19.651 | 18.631 |  |  | 18.631 | 19.172 | 19.793 | 19.935 | 20.955 |  | 19.0500 | 41.9100 | 8.5000
1/2 |  | G 1/2-14 | G 1/2-14 | 14 | B | 20.955 | 20.671 | 19.793 | 19.651 | 18.631
5/8 |  | G 5/8-14 | G 5/8-14 | 14 | A | 22.911 | 22.627 | 21.749 | 21.607 | 20.587 |  |  | 20.587 | 21.128 | 21.749 | 21.891 | 22.911 |  | 21.0000 | 45.8220 | 8.5000
5/8 |  | G 5/8-14 | G 5/8-14 | 14 | B | 22.911 | 22.627 | 21.749 | 21.607 | 20.587
3/4 |  | G 3/4-14 | G 3/4-14 | 14 | A | 26.441 | 26.157 | 25.279 | 25.137 | 24.117 |  |  | 24.117 | 24.658 | 25.279 | 25.421 | 26.441 |  | 24.5000 | 52.8820 | 8.5000
3/4 |  | G 3/4-14 | G 3/4-14 | 14 | B | 26.441 | 26.157 | 25.279 | 25.137 | 24.117
7/8 |  | G 7/8-14 | G 7/8-14 | 14 | A | 30.201 | 29.917 | 29.039 | 28.897 | 27.877 |  |  | 27.877 | 28.418 | 29.039 | 29.181 | 30.201 |  | 28.2500 | 60.4020 | 8.5000
7/8 |  | G 7/8-14 | G 7/8-14 | 14 | B | 30.201 | 29.917 | 29.039 | 28.897 | 27.877
1 |  | G 1-11 | G 1-11 | 11 | A | 33.249 | 32.889 | 31.770 | 31.590 | 30.291 |  |  | 30.291 | 30.931 | 31.77 | 31.95 | 33.249 |  | 30.7500 | 66.4980 | 10.0000
1 |  | G 1-11 | G 1-11 | 11 | B | 33.249 | 32.889 | 31.770 | 31.590 | 30.291
1 1/4 |  | G 1 1/4-11 | G 1 1/4-11 | 11 | A | 41.910 | 41.550 | 40.431 | 40.251 | 38.952 |  |  | 38.952 | 39.592 | 40.431 | 40.611 | 41.910 |  | 39.5000 | 83.8200 | 10.0000
1 1/4 |  | G 1 1/4-11 | G 1 1/4-11 | 11 | B | 41.910 | 41.550 | 40.431 | 40.251 | 38.952
1 1/2 |  | G 1 1/2-11 | G 1 1/2-11 | 11 | A | 47.803 | 47.443 | 46.324 | 46.144 | 44.845 |  |  | 44.845 | 45.485 | 46.324 | 46.504 | 47.803 |  | 45.5000 | 95.6060 | 10.0000
1 1/2 |  | G 1 1/2-11 | G 1 1/2-11 | 11 | B | 47.803 | 47.443 | 46.324 | 46.144 | 44.845
1 3/4 |  | G 1 3/4-11 | G 1 3/4-11 | 11 | A | 53.746 | 53.386 | 52.267 | 52.087 | 50.788 |  |  | 50.788 | 51.428 | 52.267 | 52.447 | 53.746 |  | 51.0000 | 107.4920 | 10.0000
1 3/4 |  | G 1 3/4-11 | G 1 3/4-11 | 11 | B | 53.746 | 53.386 | 52.267 | 52.087 | 50.788
2 |  | G 2-11 | G 2-11 | 11 | A | 59.614 | 59.254 | 58.135 | 57.955 | 56.656 |  |  | 56.656 | 57.296 | 58.135 | 58.315 | 59.614 |  | 57.0000 | 119.2280 | 10.0000
2 |  | G 2-11 | G 2-11 | 11 | B | 59.614 | 59.254 | 58.135 | 57.955 | 56.656
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

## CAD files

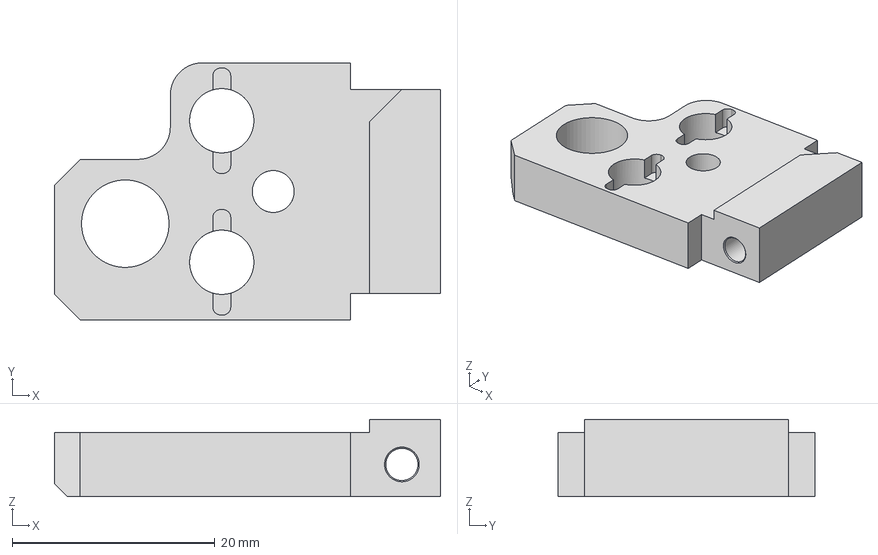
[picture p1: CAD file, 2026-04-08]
Part Drawings and Models/J005822 ANGLE ADJ UPPER Rev -.stp
38.1 x 25.4 x 7.62 mm

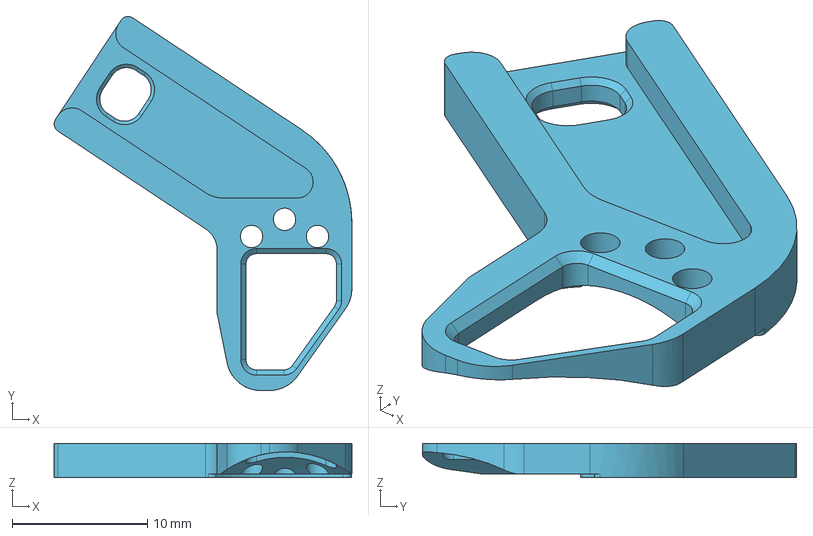
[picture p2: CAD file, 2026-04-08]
Part Drawings and Models/J005483 MBS INLINE D TAB Rev A.stp
22.0 x 27.6 x 2.54 mm

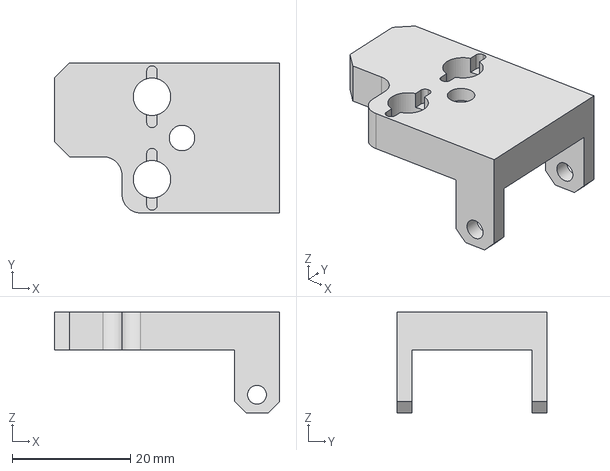
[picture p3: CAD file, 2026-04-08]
Part Drawings and Models/J005823 ANGLE ADJ LOWER Rev -.stp
38.1 x 25.4 x 17.0 mm

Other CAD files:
Pack and Go-Inventor Models/Templates/Other Default Autodesk Templates/English/am_ansi.dwg
Pack and Go-Inventor Models/Templates/Other Default Autodesk Templates/Metric/DIN.dwg
Pack and Go-Inventor Models/Templates/Standard.dwg
Pack and Go-Inventor Models/Templates/Other Default Autodesk Templates/English/ANSI (in).dwg
Pack and Go-Inventor Models/Templates/Other Default Autodesk Templates/Metric/JIS.dwg
Pack and Go-Inventor Models/Templates/Other Default Autodesk Templates/Metric/am_gb.dwg
Pack and Go-Inventor Models/Templates/Other Default Autodesk Templates/Metric/ISO.dwg
Pack and Go-Inventor Models/Templates/Other Default Autodesk Templates/Metric/am_jis.dwg
Pack and Go-Inventor Models/Templates/Other Default Autodesk Templates/Metric/BSI.dwg
Pack and Go-Inventor Models/Templates/Other Default Autodesk Templates/Metric/am_iso.dwg
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

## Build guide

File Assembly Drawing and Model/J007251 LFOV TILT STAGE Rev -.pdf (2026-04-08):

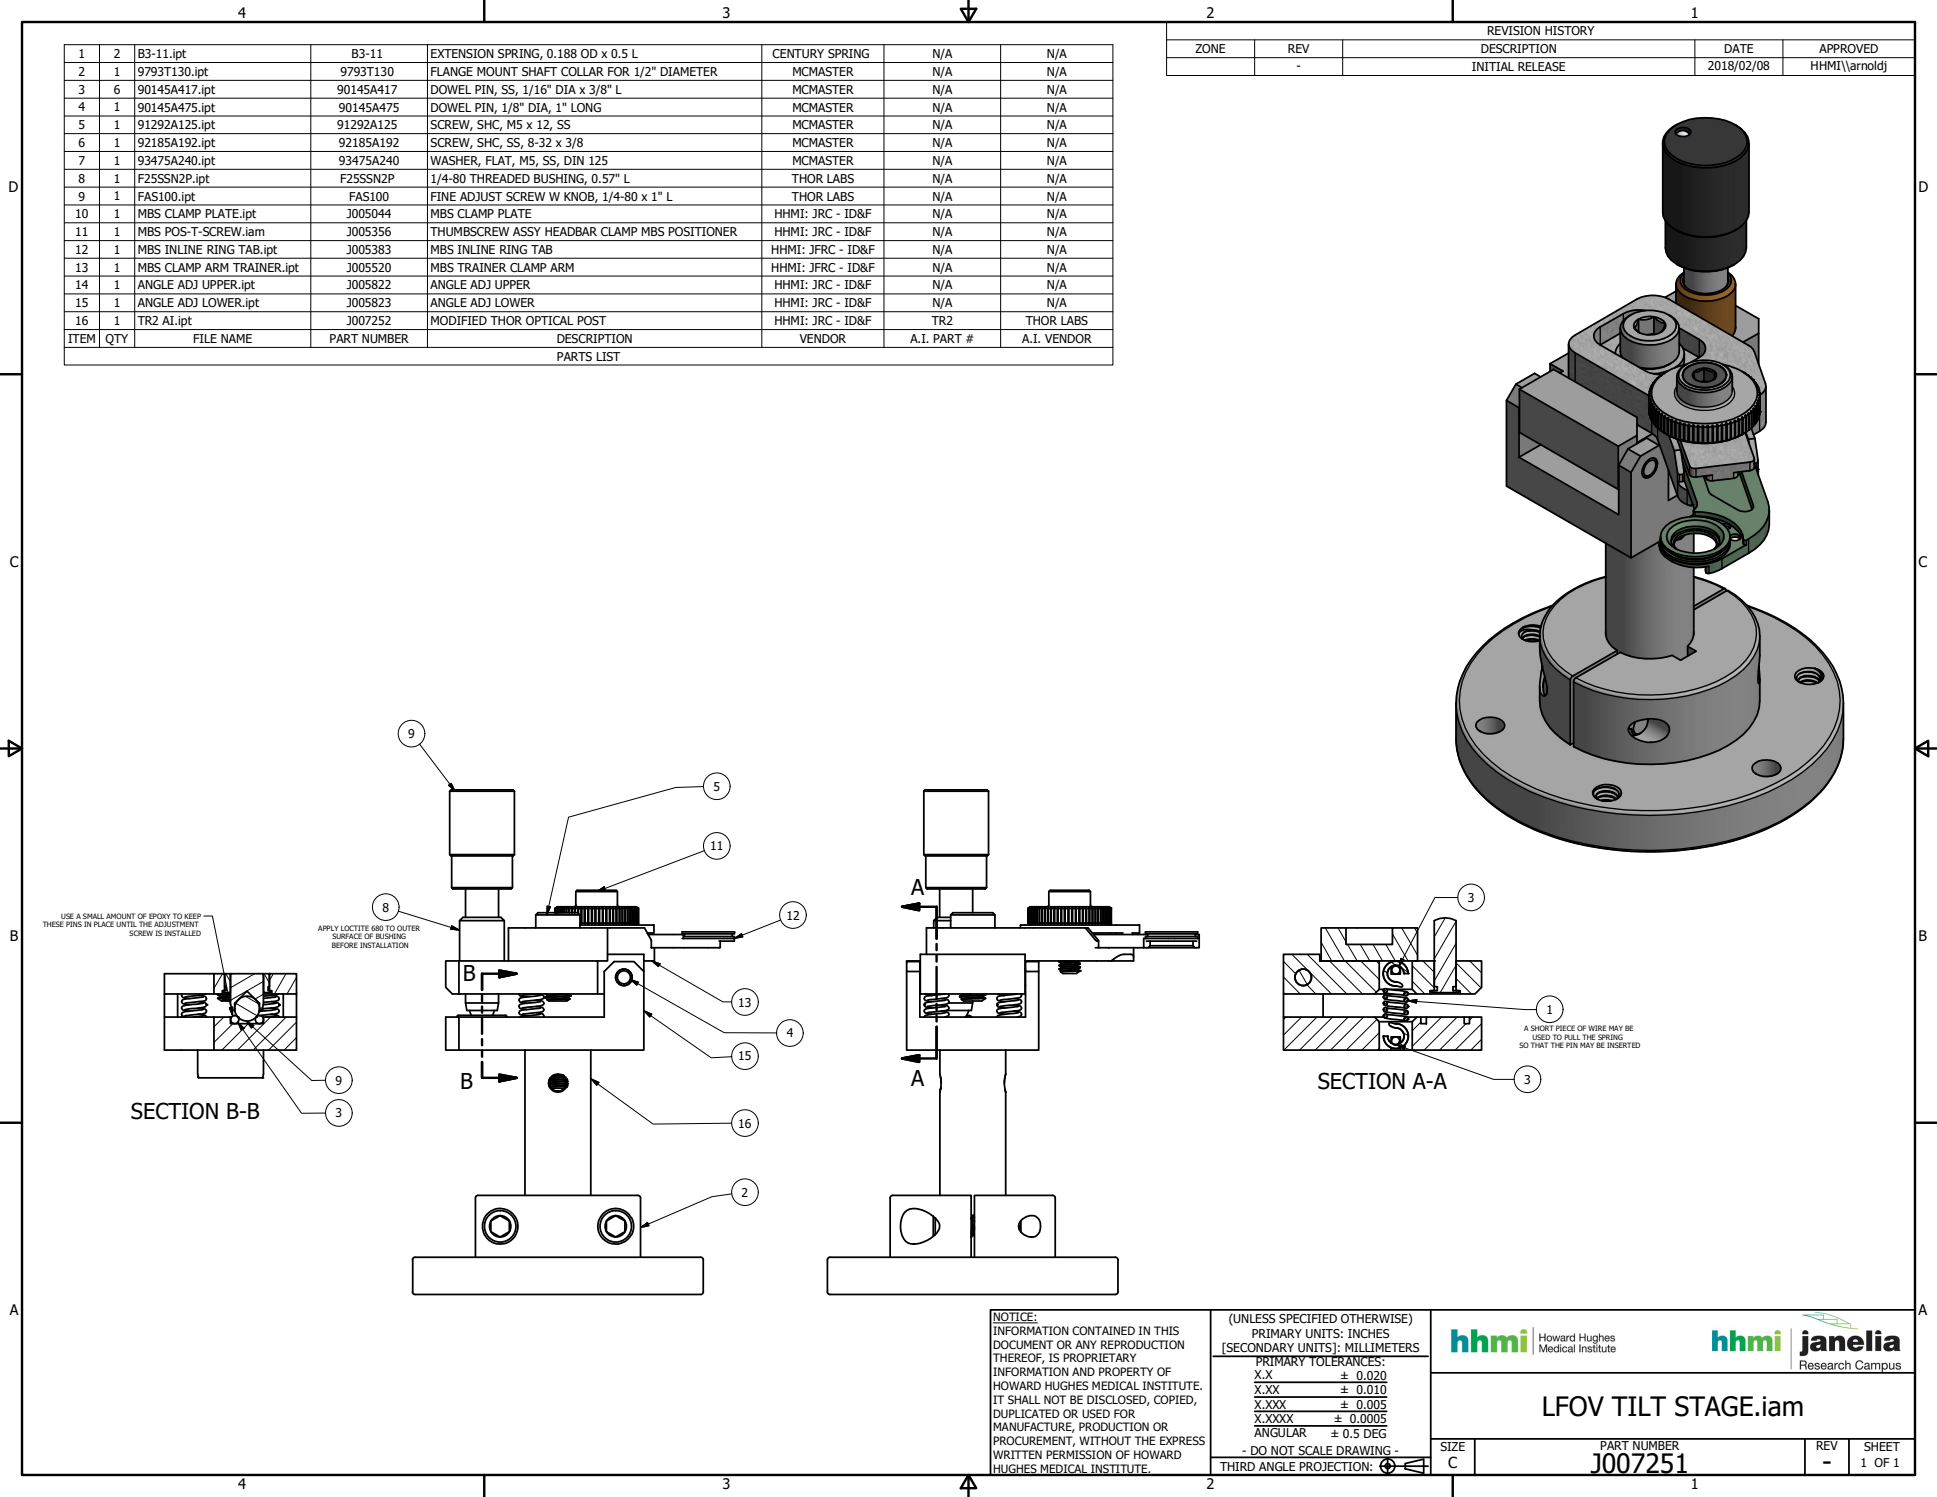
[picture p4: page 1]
SECTION A-A; SECTION B-B; PARTS LIST; PART NUMBER; 1 OF 1 THIRD ANGLE PROJECTION:; ± 0.020 ± 0.010 ± 0.005 ± 0.0005 ± 0.5 DEG; REVISION HISTORY

ZONE | REV | DESCRIPTION | DATE | APPROVED

1 | 2 | B3-11.ipt | B3-11 | EXTENSION SPRING, 0.188 OD x 0.5 L | CENTURY SPRING | N/A | N/A
2 | 1 | 9793T130.ipt | 9793T130 | FLANGE MOUNT SHAFT COLLAR FOR 1/2" DIAMETER | MCMASTER | N/A | N/A
3 | 6 | 90145A417.ipt | 90145A417 | DOWEL PIN, SS, 1/16" DIA x 3/8" L | MCMASTER | N/A | N/A
4 | 1 | 90145A475.ipt | 90145A475 | DOWEL PIN, 1/8" DIA, 1" LONG | MCMASTER | N/A | N/A
5 | 1 | 91292A125.ipt | 91292A125 | SCREW, SHC, M5 x 12, SS | MCMASTER | N/A | N/A
6 | 1 | 92185A192.ipt | 92185A192 | SCREW, SHC, SS, 8-32 x 3/8 | MCMASTER | N/A | N/A
7 | 1 | 93475A240.ipt | 93475A240 | WASHER, FLAT, M5, SS, DIN 125 | MCMASTER | N/A | N/A
8 | 1 | F25SSN2P.ipt | F25SSN2P | 1/4-80 THREADED BUSHING, 0.57" L | THOR LABS | N/A | N/A
9 | 1 | FAS100.ipt | FAS100 | FINE ADJUST SCREW W KNOB, 1/4-80 x 1" L | THOR LABS | N/A | N/A
10 | 1 | MBS CLAMP PLATE.ipt | J005044 | MBS CLAMP PLATE | HHMI: JRC - ID&F | N/A | N/A
11 | 1 | MBS POS-T-SCREW.iam | J005356 | THUMBSCREW ASSY HEADBAR CLAMP MBS POSITIONER | HHMI: JRC - ID&F | N/A | N/A
12 | 1 | MBS INLINE RING TAB.ipt | J005383 | MBS INLINE RING TAB | HHMI: JFRC - ID&F | N/A | N/A
13 | 1 | MBS CLAMP ARM TRAINER.ipt | J005520 | MBS TRAINER CLAMP ARM | HHMI: JFRC - ID&F | N/A | N/A
14 | 1 | ANGLE ADJ UPPER.ipt | J005822 | ANGLE ADJ UPPER | HHMI: JRC - ID&F | N/A | N/A
15 | 1 | ANGLE ADJ LOWER.ipt | J005823 | ANGLE ADJ LOWER | HHMI: JRC - ID&F | N/A | N/A
16 | 1 | TR2 AI.ipt | J007252 | MODIFIED THOR OPTICAL POST | HHMI: JRC - ID&F | TR2 | THOR LABS
ITEM | QTY | FILE NAME | PART NUMBER | DESCRIPTION | VENDOR | A.I. PART # | A.I. VENDOR

- | INITIAL RELEASE | 2018/02/08 | HHMI\\arnoldj

USE A SMALL AMOUNT OF EPOXY TO KEEP
THESE PINS IN PLACE UNTIL THE ADJUSTMENT

SCREW IS INSTALLED

APPLY LOCTITE 680 TO OUTER
SURFACE OF BUSHING
BEFORE INSTALLATION

A SHORT PIECE OF WIRE MAY BE
USED TO PULL THE SPRING
SO THAT THE PIN MAY BE INSERTED

NOTICE:
INFORMATION CONTAINED IN THIS
DOCUMENT OR ANY REPRODUCTION
THEREOF, IS PROPRIETARY
INFORMATION AND PROPERTY OF
HOWARD HUGHES MEDICAL INSTITUTE.
IT SHALL NOT BE DISCLOSED, COPIED,
DUPLICATED OR USED FOR
MANUFACTURE, PRODUCTION OR
PROCUREMENT, WITHOUT THE EXPRESS
WRITTEN PERMISSION OF HOWARD
HUGHES MEDICAL INSTITUTE.

(UNLESS SPECIFIED OTHERWISE)
PRIMARY UNITS: INCHES
[SECONDARY UNITS]: MILLIMETERS
PRIMARY TOLERANCES:
X.XXX
X.XXXX
ANGULAR
- DO NOT SCALE DRAWING -

LFOV TILT STAGE.iam

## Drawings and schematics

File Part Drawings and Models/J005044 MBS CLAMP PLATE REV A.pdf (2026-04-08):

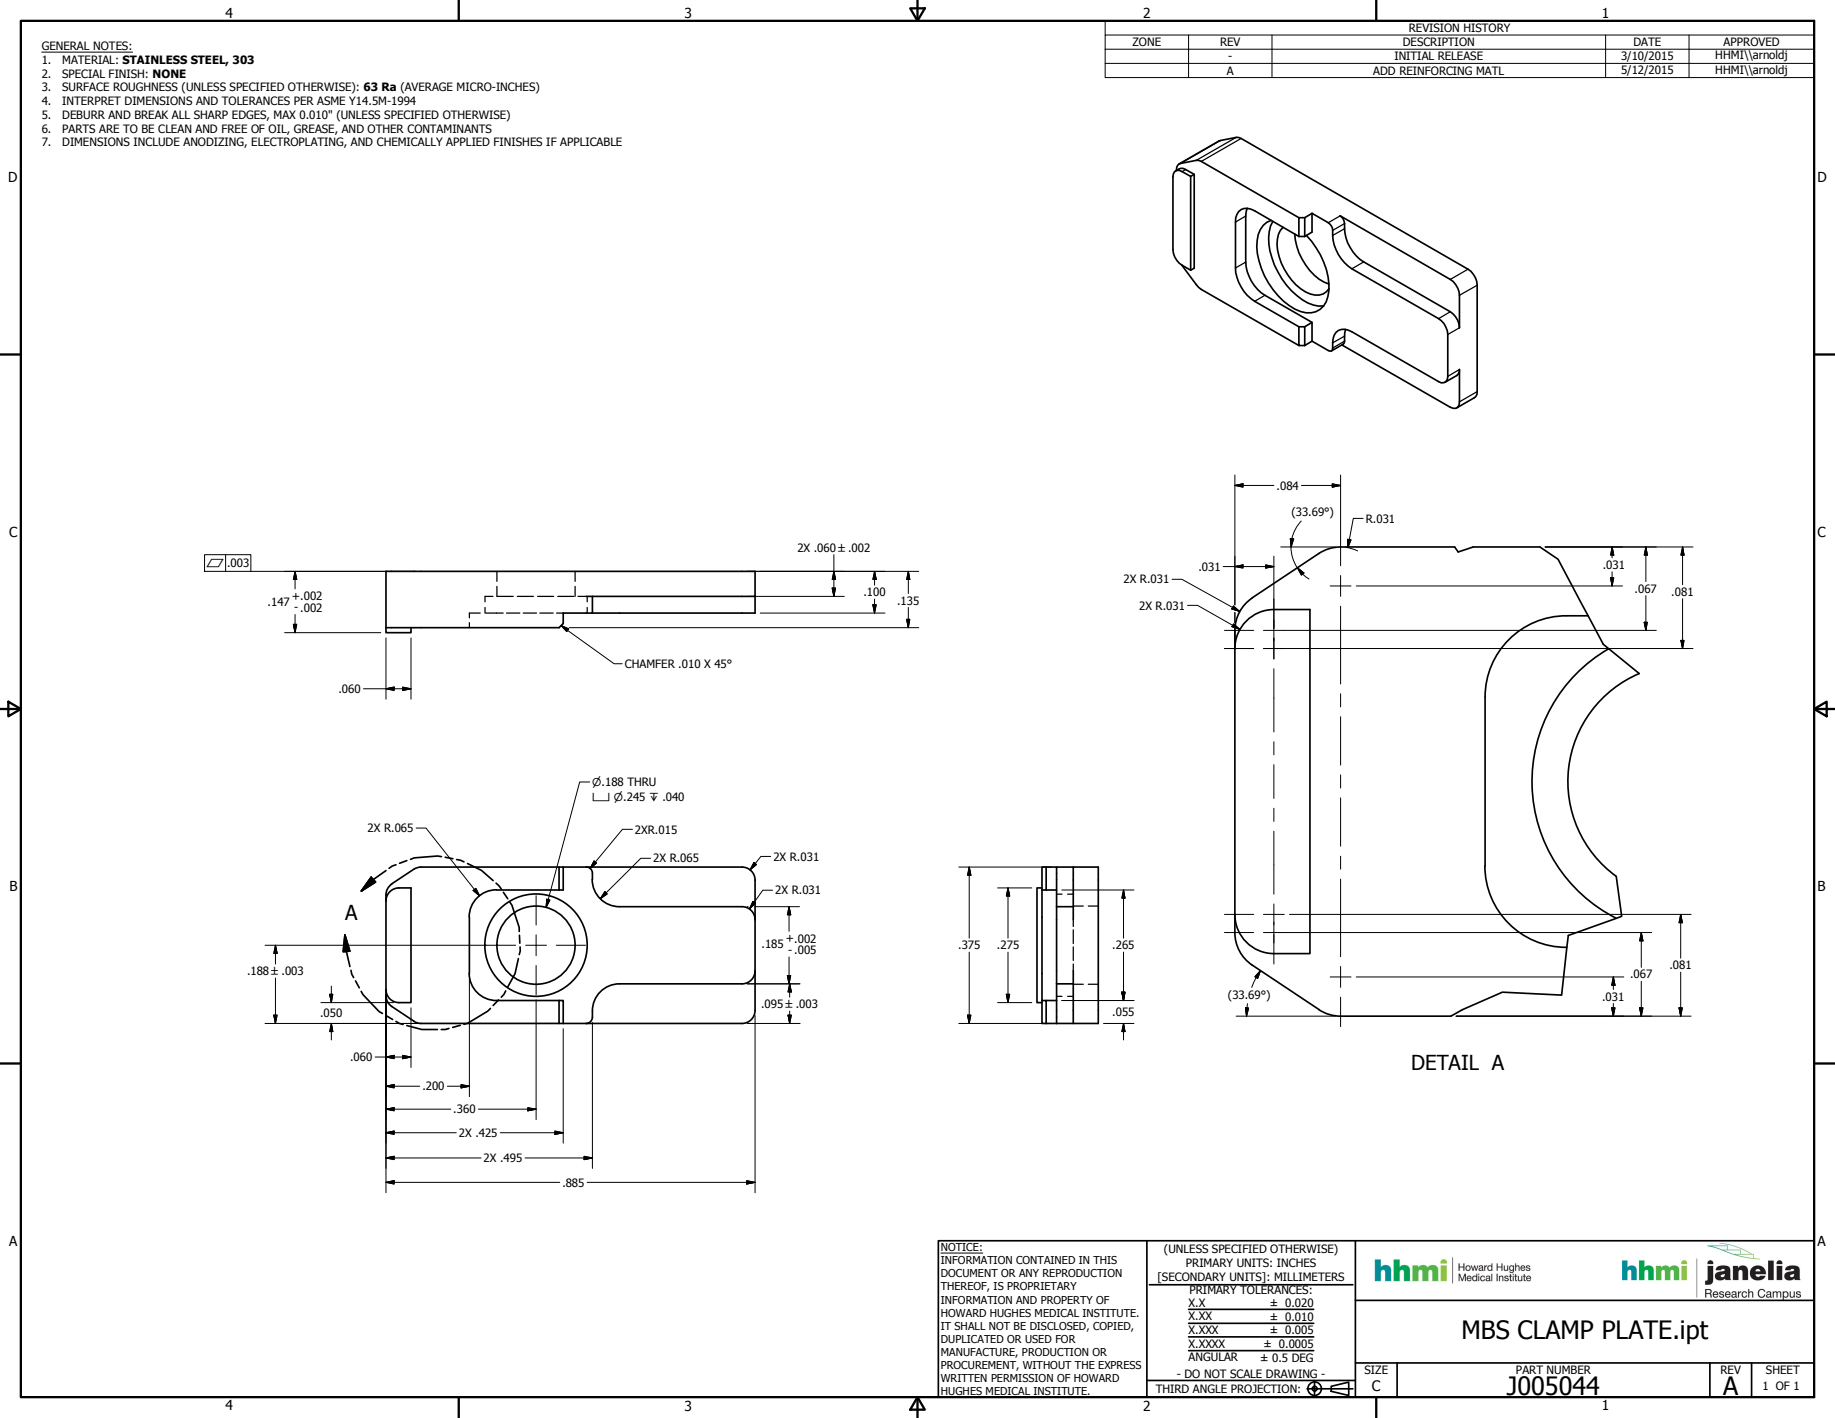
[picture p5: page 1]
DETAIL A; PART NUMBER; SIZE; REV; SHEET; 1 OF 1 THIRD ANGLE PROJECTION:; ± 0.020 ± 0.010 ± 0.005 ± 0.0005 ± 0.5 DEG; REVISION HISTORY; ZONE; DESCRIPTION; DATE; APPROVED; INITIAL RELEASE; HHMI\\arnoldj; ADD REINFORCING MATL; P.188 THRU X P.245 Z .040; CHAMFER .010 X 45°

GENERAL NOTES:
1. MATERIAL: STAINLESS STEEL, 303
2. SPECIAL FINISH: NONE
3. SURFACE ROUGHNESS (UNLESS SPECIFIED OTHERWISE): 63 Ra (AVERAGE MICRO-INCHES)
4. INTERPRET DIMENSIONS AND TOLERANCES PER ASME Y14.5M-1994
5. DEBURR AND BREAK ALL SHARP EDGES, MAX 0.010" (UNLESS SPECIFIED OTHERWISE)
6. PARTS ARE TO BE CLEAN AND FREE OF OIL, GREASE, AND OTHER CONTAMINANTS
7. DIMENSIONS INCLUDE ANODIZING, ELECTROPLATING, AND CHEMICALLY APPLIED FINISHES IF APPLICABLE

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

MBS CLAMP PLATE.ipt

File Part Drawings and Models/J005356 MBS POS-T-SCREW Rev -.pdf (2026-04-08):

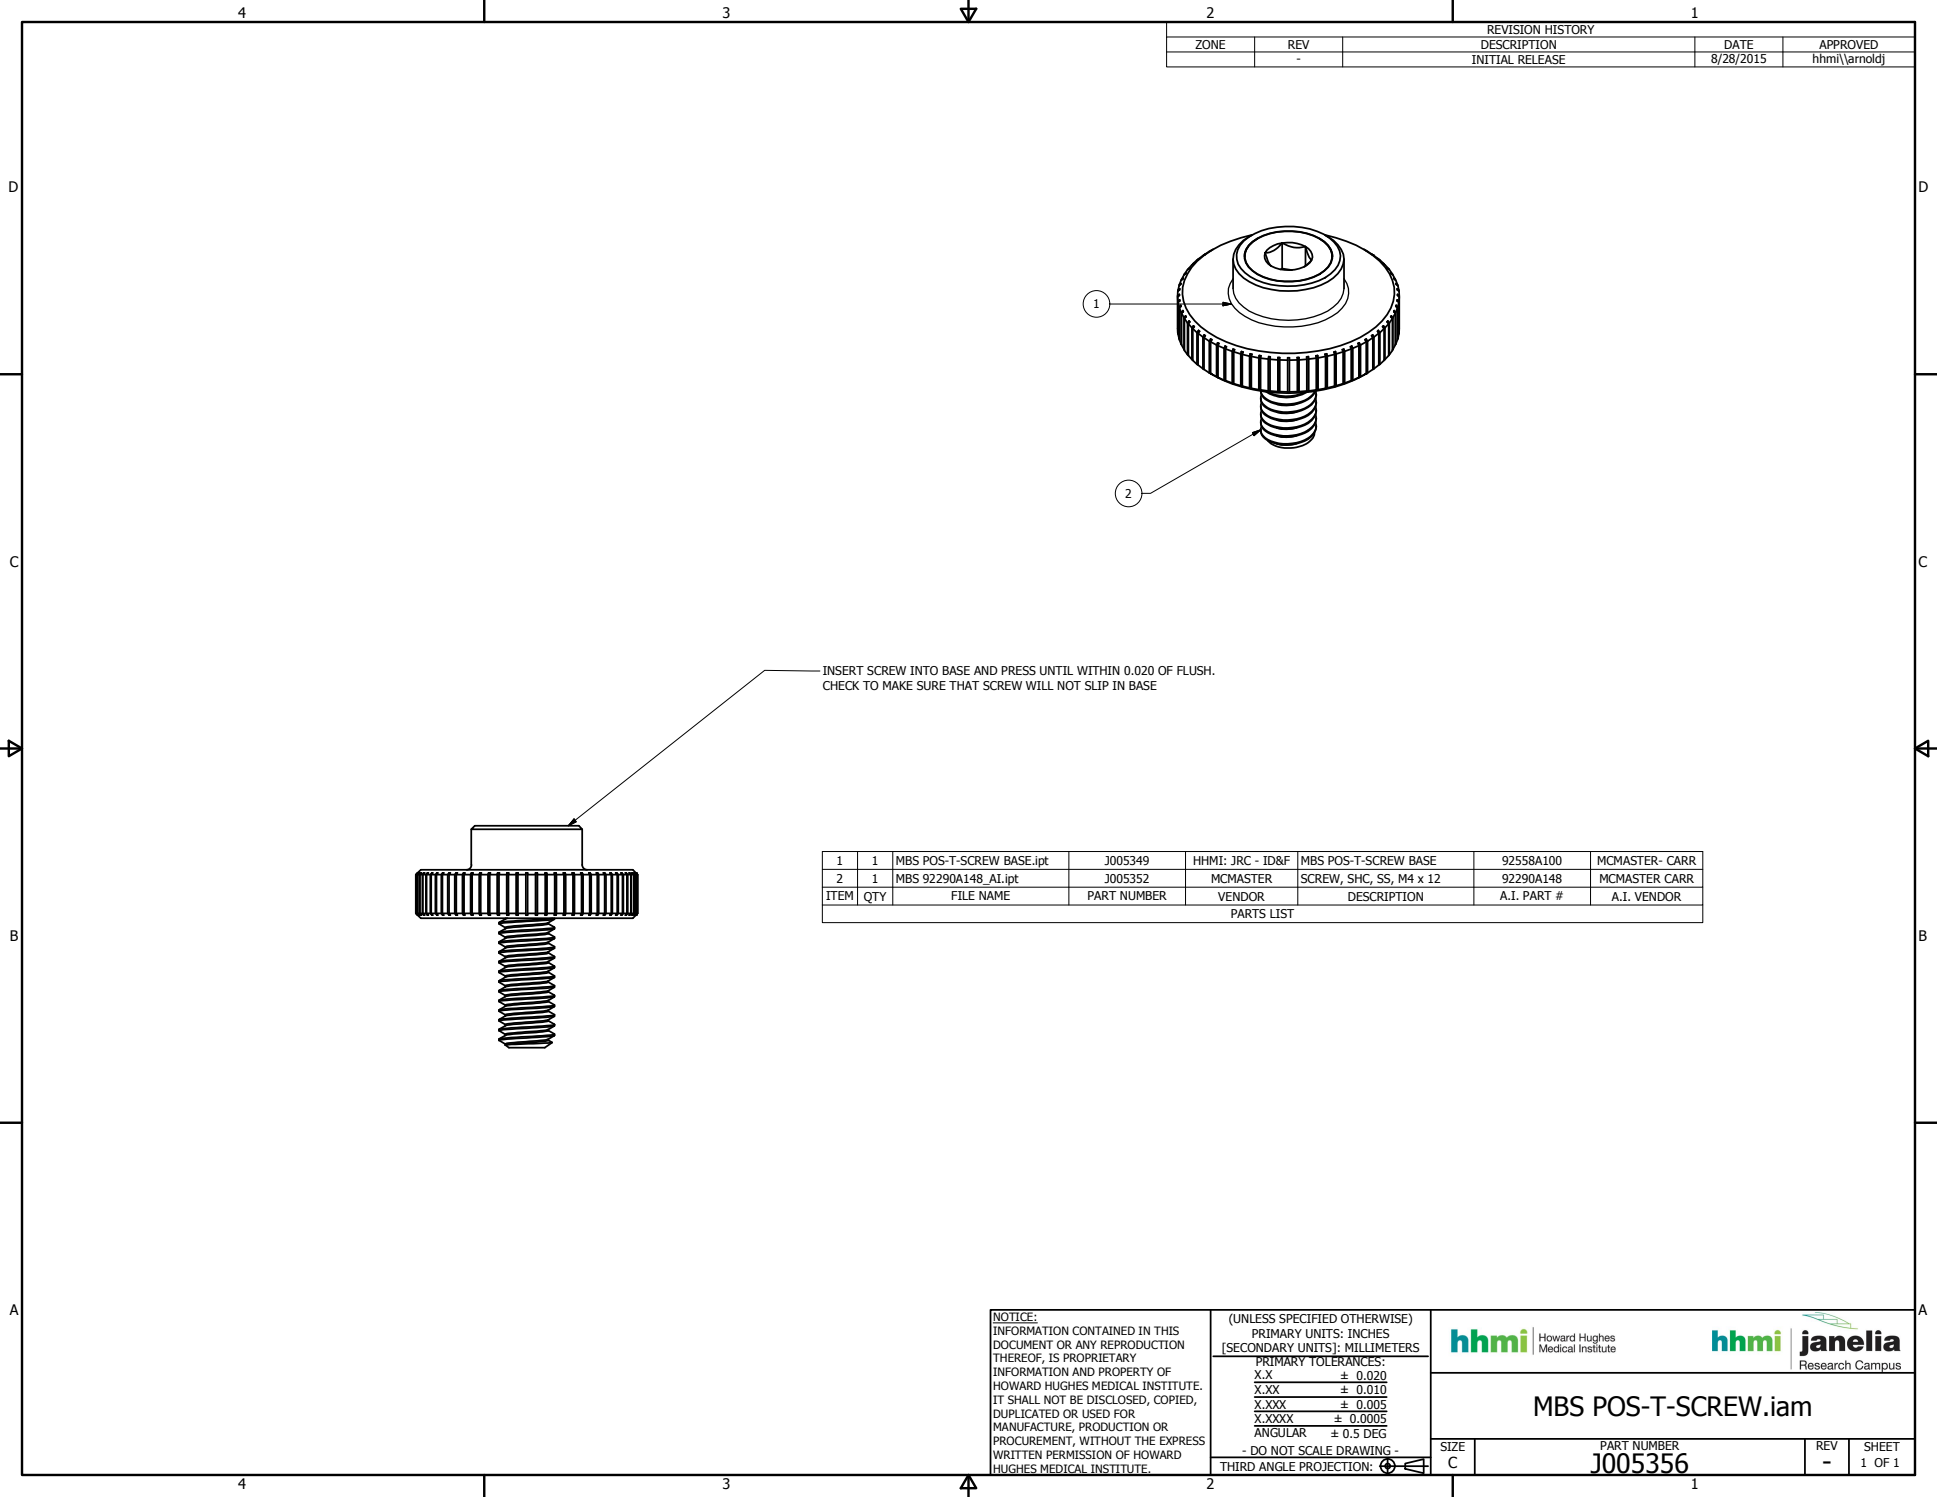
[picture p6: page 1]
MBS POS-T-SCREW BASE.ipt; HHMI: JRC - ID&F; MBS POS-T-SCREW BASE; MCMASTER- CARR; MBS 92290A148_AI.ipt; MCMASTER; SCREW, SHC, SS, M4 x 12; MCMASTER CARR; PARTS LIST; ITEM; QTY; FILE NAME; PART NUMBER; VENDOR; DESCRIPTION; A.I. PART #; A.I. VENDOR; SIZE; REV; SHEET; 1 OF 1 THIRD ANGLE PROJECTION:; ± 0.020 ± 0.010 ± 0.005 ± 0.0005 ± 0.5 DEG; REVISION HISTORY; ZONE; DATE; APPROVED; INITIAL RELEASE; hhmi\\arnoldj

INSERT SCREW INTO BASE AND PRESS UNTIL WITHIN 0.020 OF FLUSH.
CHECK TO MAKE SURE THAT SCREW WILL NOT SLIP IN BASE

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

MBS POS-T-SCREW.iam

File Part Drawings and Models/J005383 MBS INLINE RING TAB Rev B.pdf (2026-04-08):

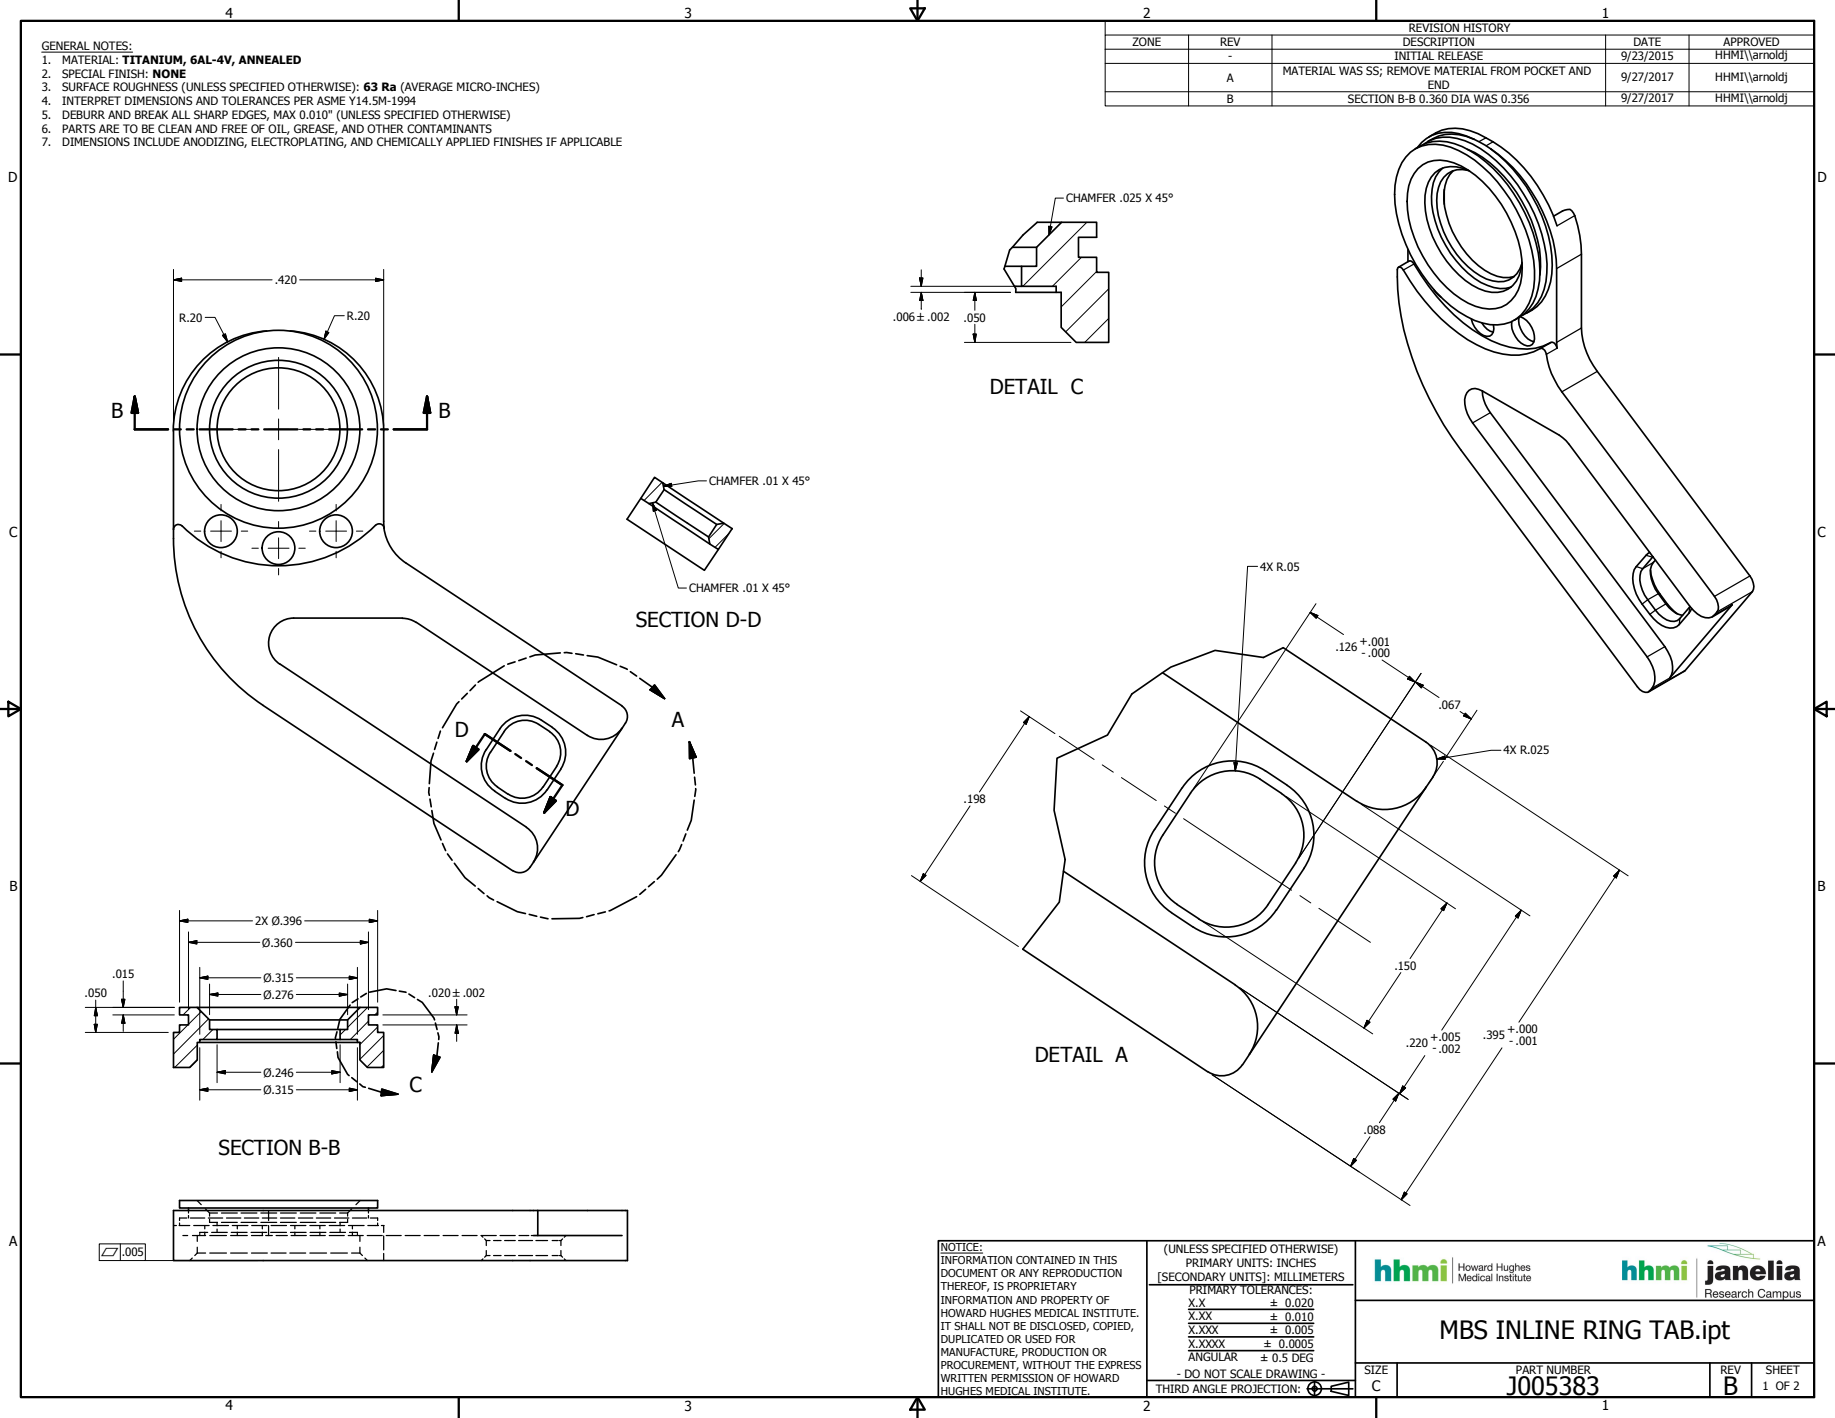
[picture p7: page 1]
DETAIL A; SECTION B-B; DETAIL C; SECTION D-D; PART NUMBER; SIZE; REV; SHEET; 1 OF 2 THIRD ANGLE PROJECTION:; ± 0.020 ± 0.010 ± 0.005 ± 0.0005 ± 0.5 DEG; REVISION HISTORY; ZONE; DESCRIPTION; DATE; APPROVED; INITIAL RELEASE; HHMI\\arnoldj; END; SECTION B-B 0.360 DIA WAS 0.356; CHAMFER .025 X 45°; CHAMFER .01 X 45°

GENERAL NOTES:
1. MATERIAL: TITANIUM, 6AL-4V, ANNEALED
2. SPECIAL FINISH: NONE
3. SURFACE ROUGHNESS (UNLESS SPECIFIED OTHERWISE): 63 Ra (AVERAGE MICRO-INCHES)
4. INTERPRET DIMENSIONS AND TOLERANCES PER ASME Y14.5M-1994
5. DEBURR AND BREAK ALL SHARP EDGES, MAX 0.010" (UNLESS SPECIFIED OTHERWISE)
6. PARTS ARE TO BE CLEAN AND FREE OF OIL, GREASE, AND OTHER CONTAMINANTS
7. DIMENSIONS INCLUDE ANODIZING, ELECTROPLATING, AND CHEMICALLY APPLIED FINISHES IF APPLICABLE

MATERIAL WAS SS; REMOVE MATERIAL FROM POCKET AND

NOTICE:
INFORMATION CONTAINED IN THIS
DOCUMENT OR ANY REPRODUCTION
THEREOF, IS PROPRIETARY
INFORMATION AND PROPERTY OF
HOWARD HUGHES MEDICAL INSTITUTE.
IT SHALL NOT BE DISCLOSED, COPIED,
DUPLICATED OR USED FOR
MANUFACTURE, PRODUCTION OR
PROCUREMENT, WITHOUT THE EXPRESS
WRITTEN PERMISSION OF HOWARD
HUGHES MEDICAL INSTITUTE.

(UNLESS SPECIFIED OTHERWISE)
PRIMARY UNITS: INCHES
[SECONDARY UNITS]: MILLIMETERS
PRIMARY TOLERANCES:
X.XXX
X.XXXX
ANGULAR
- DO NOT SCALE DRAWING -

MBS INLINE RING TAB.ipt

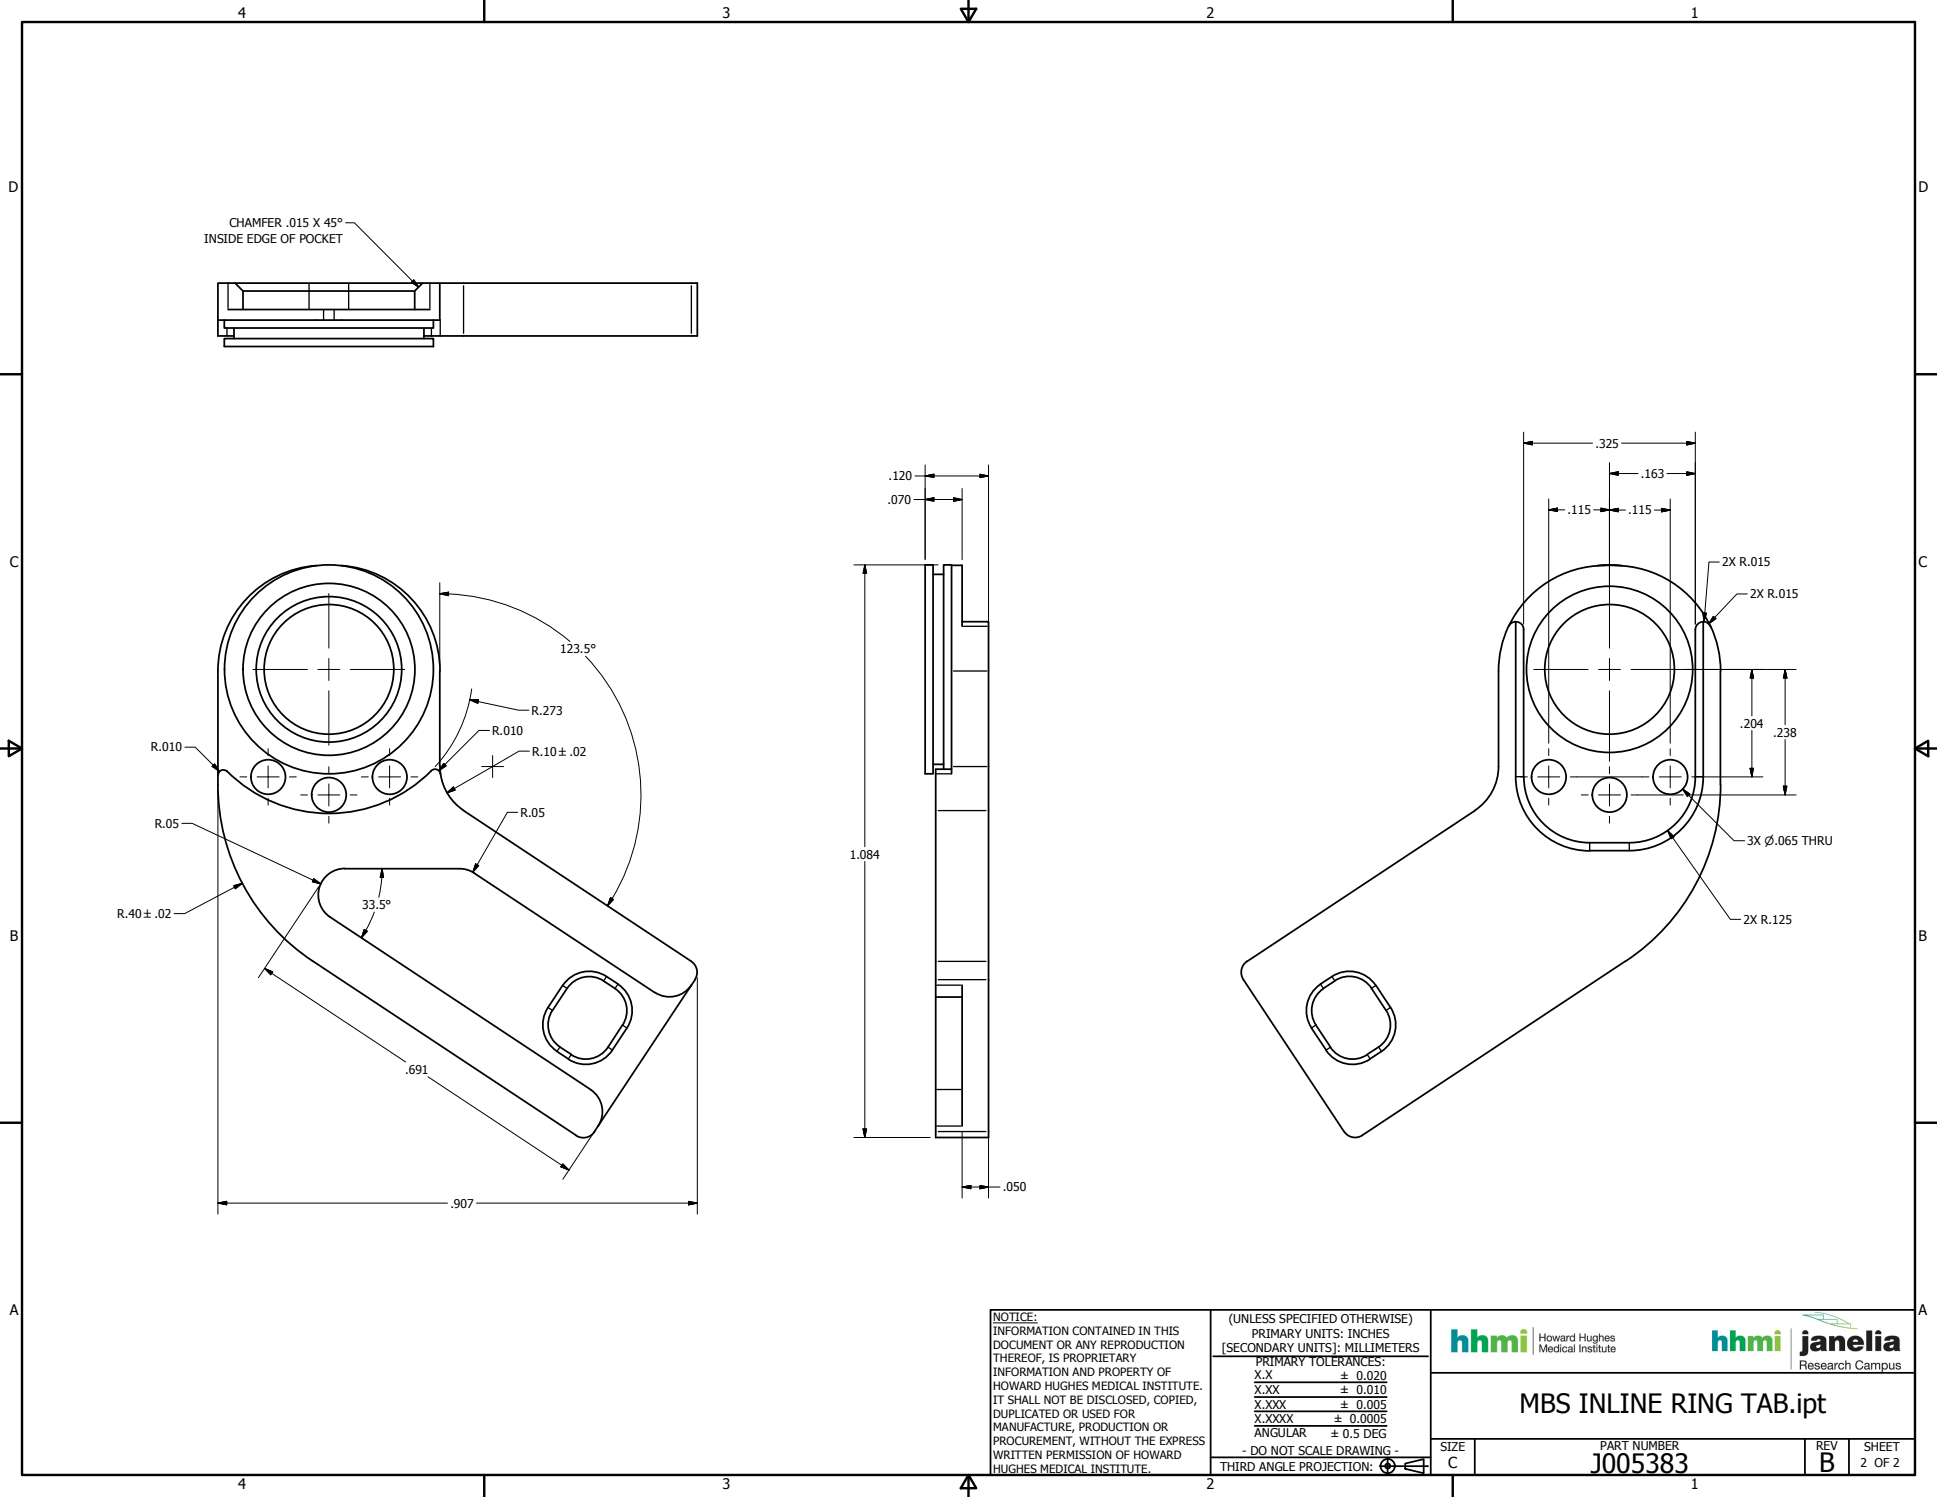
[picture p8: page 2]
PART NUMBER; SIZE; REV; SHEET; 2 OF 2 THIRD ANGLE PROJECTION:; ± 0.020 ± 0.010 ± 0.005 ± 0.0005 ± 0.5 DEG; 3X P.065 THRU

CHAMFER .015 X 45°
INSIDE EDGE OF POCKET

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

MBS INLINE RING TAB.ipt

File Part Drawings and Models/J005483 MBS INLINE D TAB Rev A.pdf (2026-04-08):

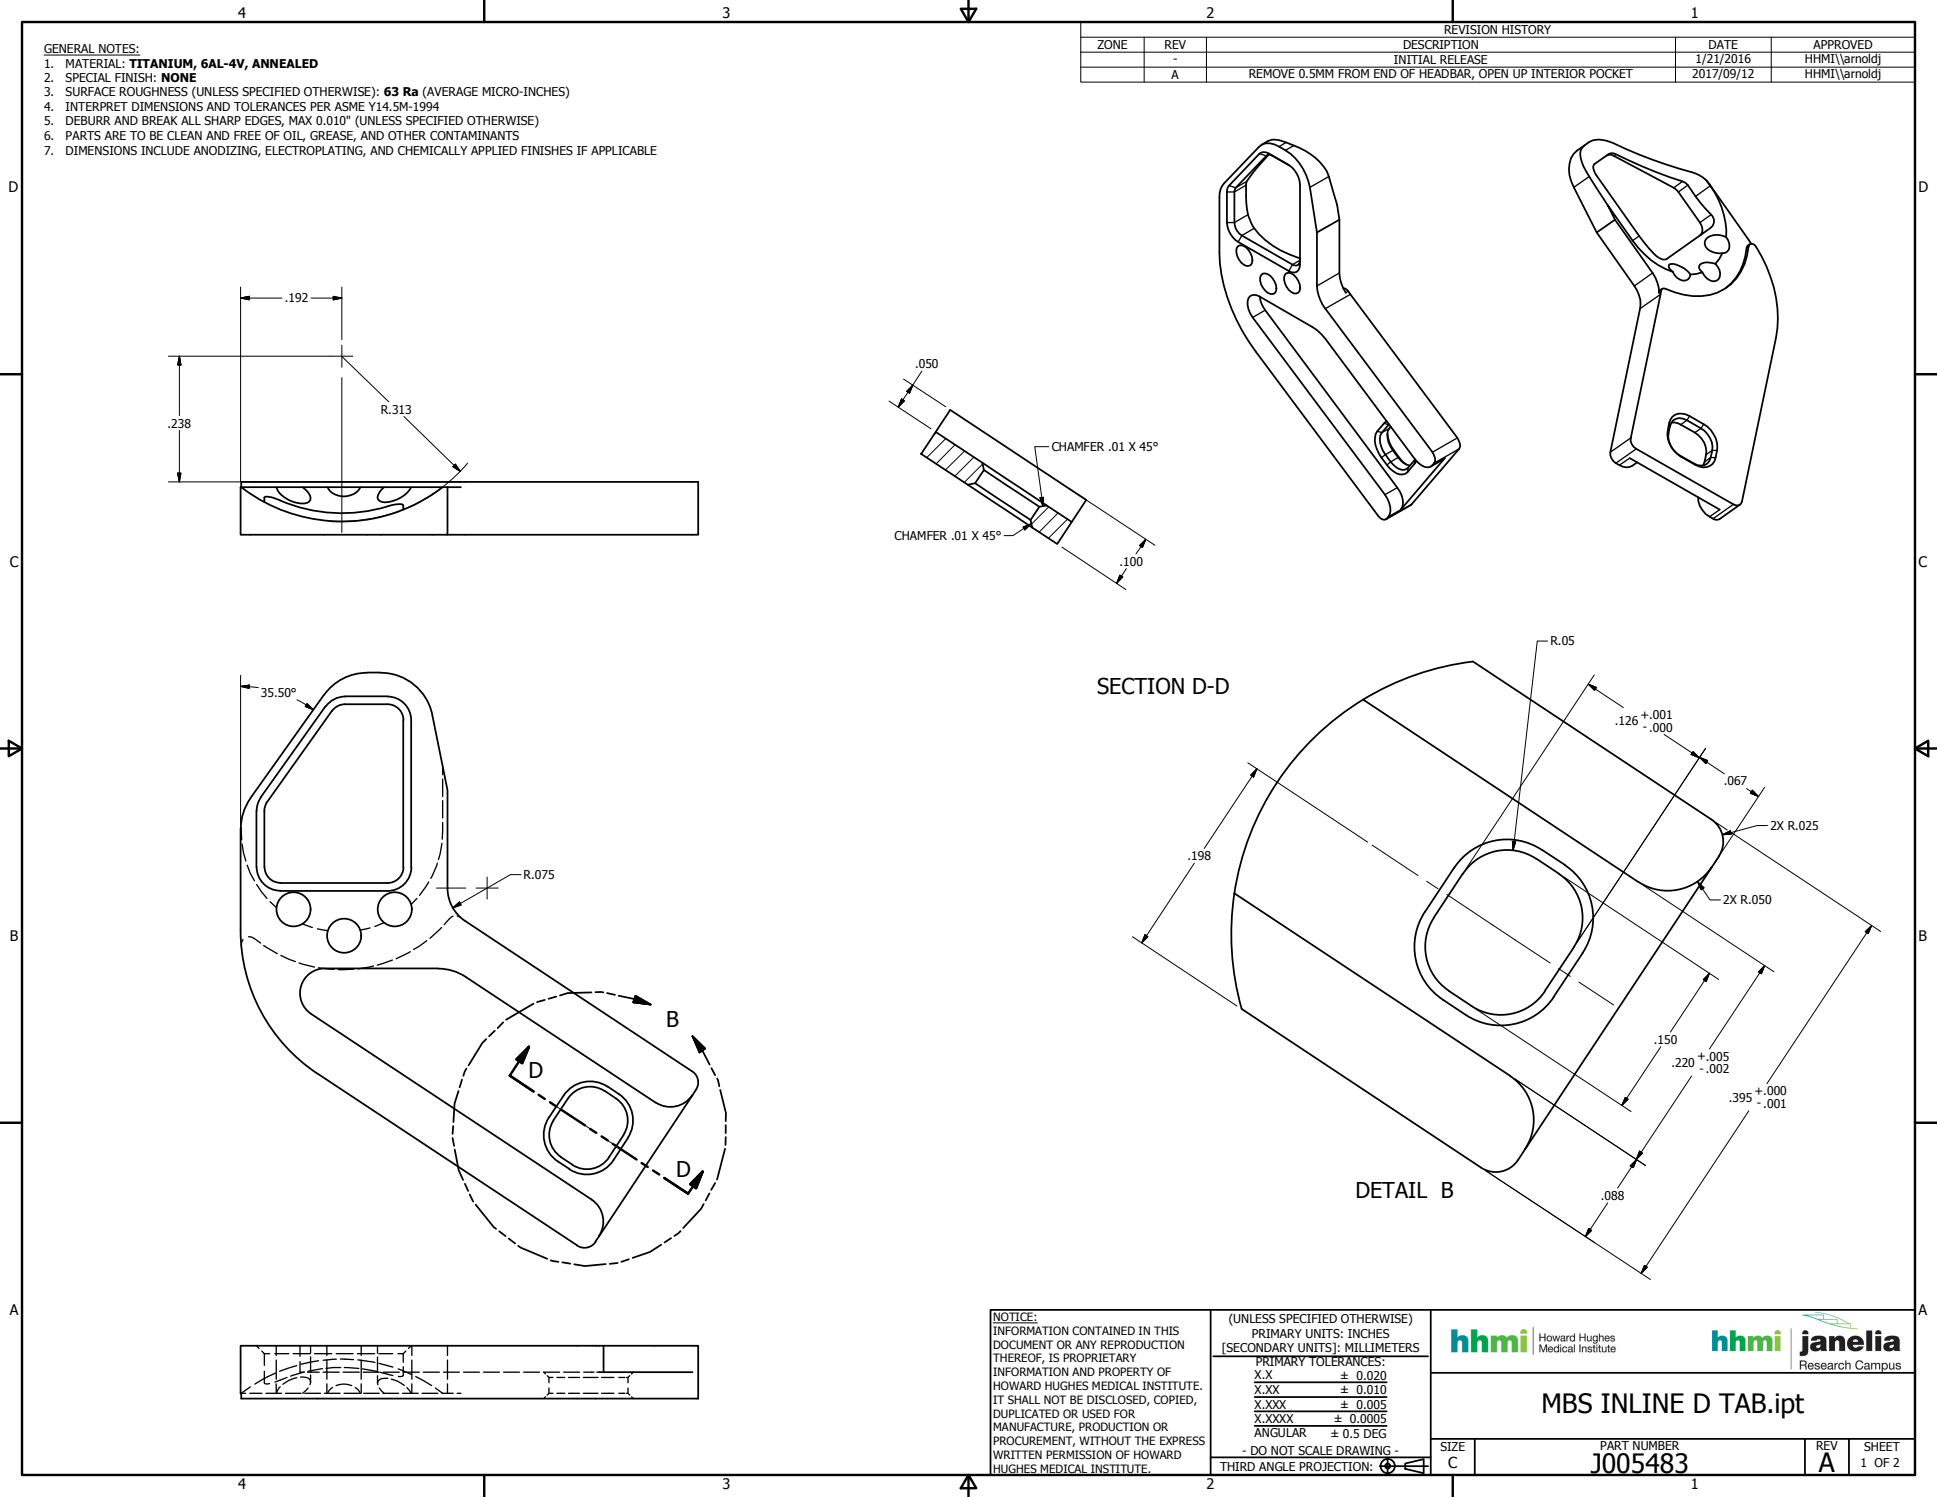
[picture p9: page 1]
DETAIL B; SECTION D-D; PART NUMBER; SIZE; REV; SHEET; 1 OF 2 THIRD ANGLE PROJECTION:; ± 0.020 ± 0.010 ± 0.005 ± 0.0005 ± 0.5 DEG; REVISION HISTORY; ZONE; DESCRIPTION; DATE; APPROVED; INITIAL RELEASE; HHMI\\arnoldj; REMOVE 0.5MM FROM END OF HEADBAR, OPEN UP INTERIOR POCKET; CHAMFER .01 X 45°

GENERAL NOTES:
1. MATERIAL: TITANIUM, 6AL-4V, ANNEALED
2. SPECIAL FINISH: NONE
3. SURFACE ROUGHNESS (UNLESS SPECIFIED OTHERWISE): 63 Ra (AVERAGE MICRO-INCHES)
4. INTERPRET DIMENSIONS AND TOLERANCES PER ASME Y14.5M-1994
5. DEBURR AND BREAK ALL SHARP EDGES, MAX 0.010" (UNLESS SPECIFIED OTHERWISE)
6. PARTS ARE TO BE CLEAN AND FREE OF OIL, GREASE, AND OTHER CONTAMINANTS
7. DIMENSIONS INCLUDE ANODIZING, ELECTROPLATING, AND CHEMICALLY APPLIED FINISHES IF APPLICABLE

NOTICE:
INFORMATION CONTAINED IN THIS
DOCUMENT OR ANY REPRODUCTION
THEREOF, IS PROPRIETARY
INFORMATION AND PROPERTY OF
HOWARD HUGHES MEDICAL INSTITUTE.
IT SHALL NOT BE DISCLOSED, COPIED,
DUPLICATED OR USED FOR
MANUFACTURE, PRODUCTION OR
PROCUREMENT, WITHOUT THE EXPRESS
WRITTEN PERMISSION OF HOWARD
HUGHES MEDICAL INSTITUTE.

(UNLESS SPECIFIED OTHERWISE)
PRIMARY UNITS: INCHES
[SECONDARY UNITS]: MILLIMETERS
PRIMARY TOLERANCES:
X.XXX
X.XXXX
ANGULAR
- DO NOT SCALE DRAWING -

MBS INLINE D TAB.ipt

E

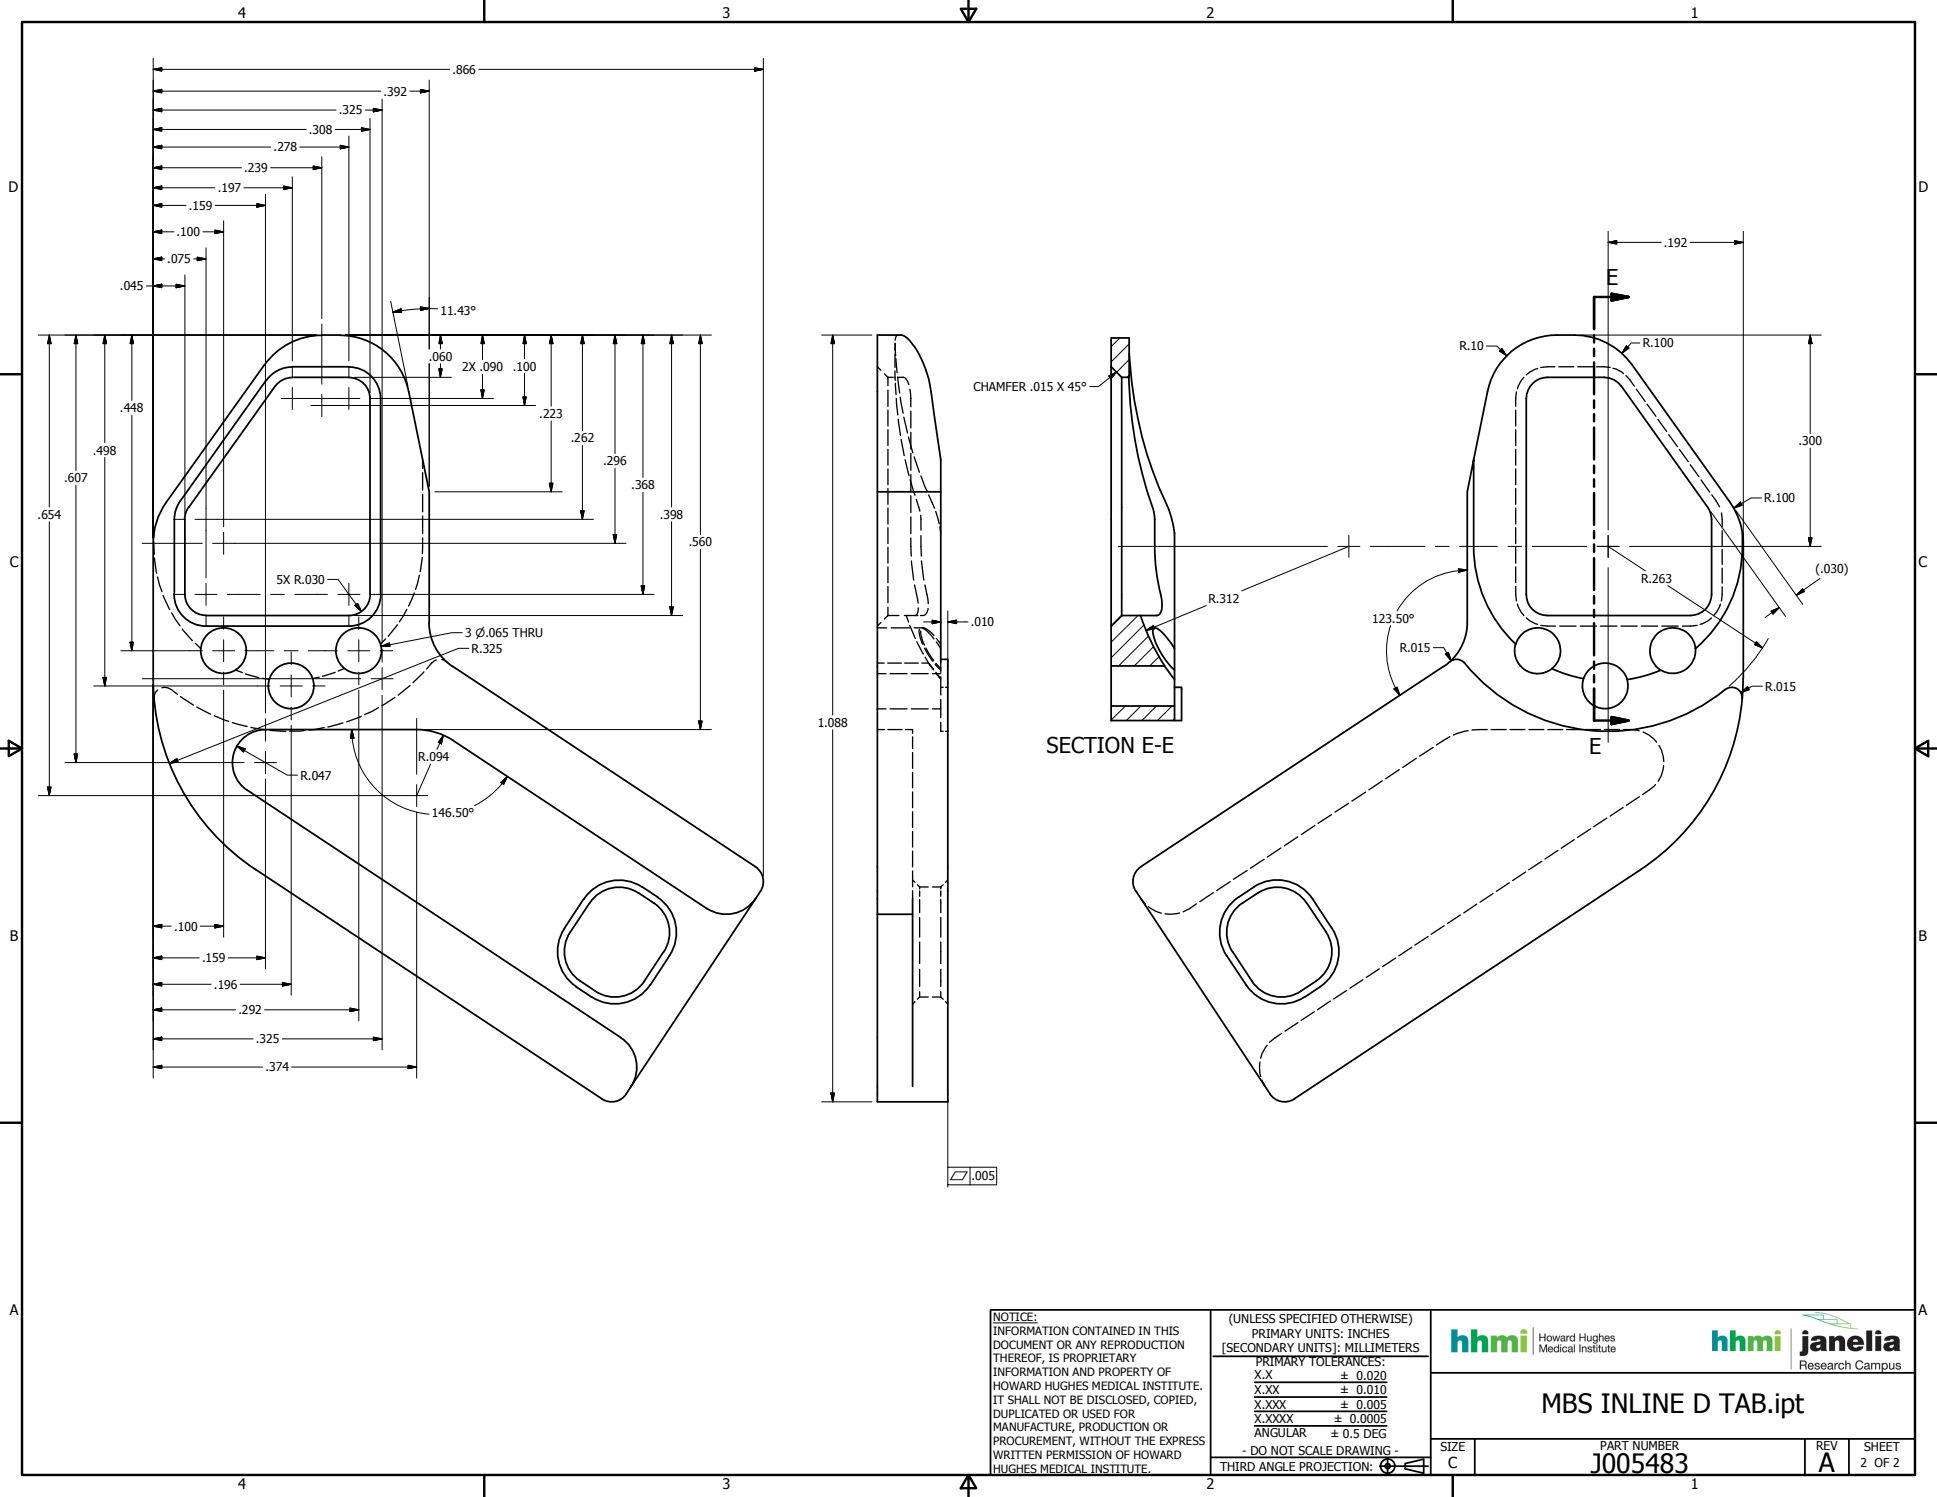
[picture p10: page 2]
SECTION E-E; PART NUMBER; SIZE; REV; SHEET; 2 OF 2 THIRD ANGLE PROJECTION:; ± 0.020 ± 0.010 ± 0.005 ± 0.0005 ± 0.5 DEG; 3 P.065 THRU; CHAMFER .015 X 45°

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

MBS INLINE D TAB.ipt

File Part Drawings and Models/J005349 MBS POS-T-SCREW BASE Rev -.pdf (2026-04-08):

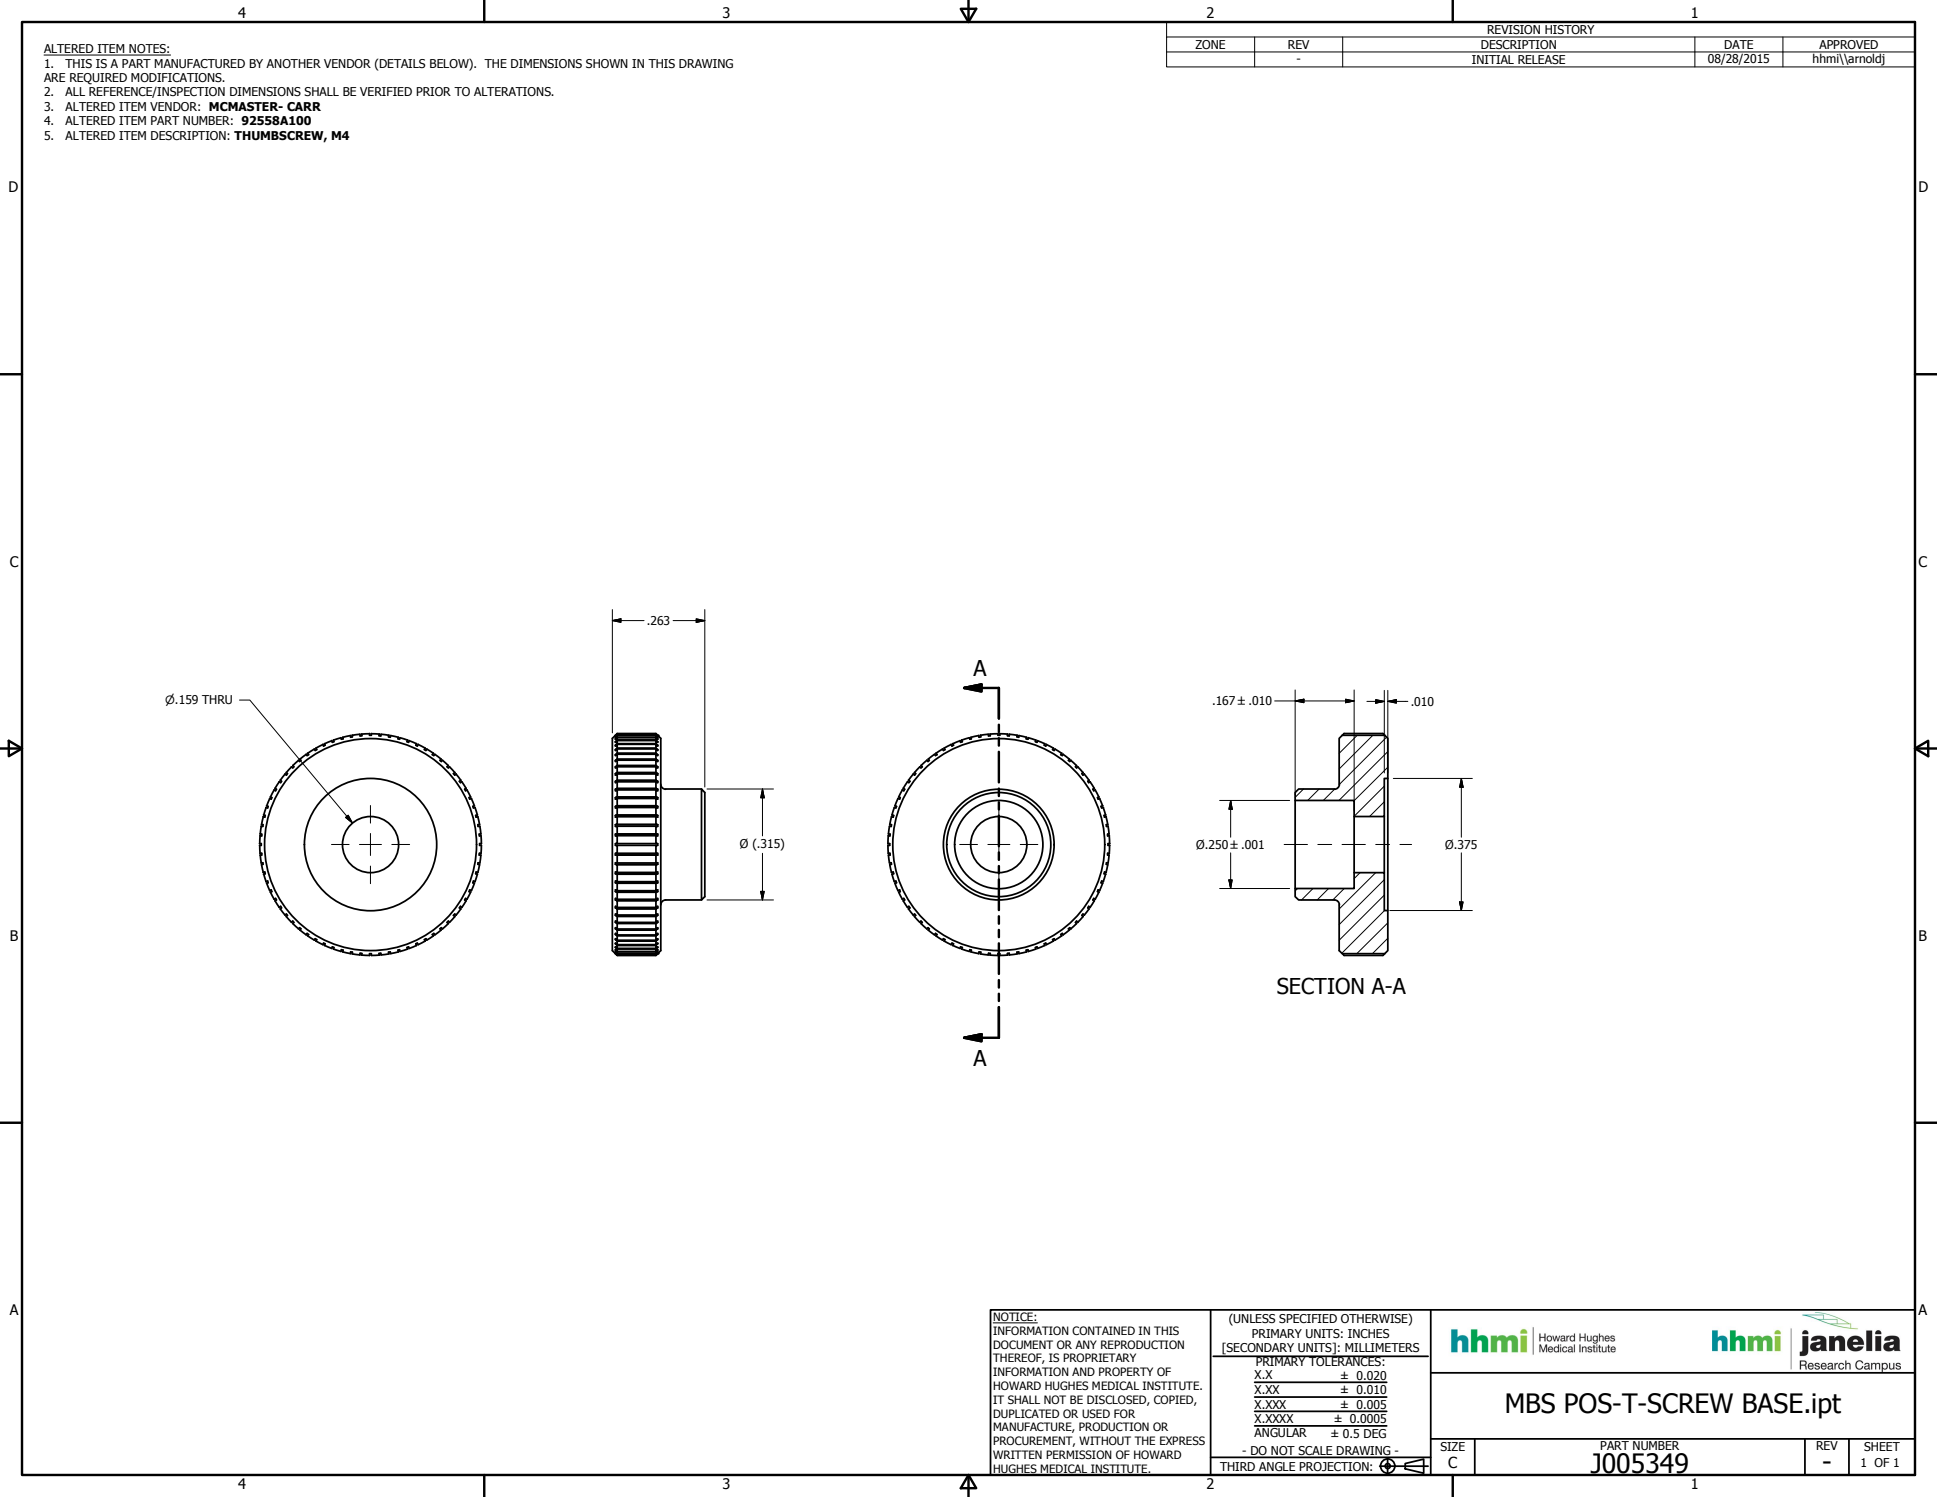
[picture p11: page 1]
SECTION A-A; PART NUMBER; SIZE; REV; SHEET; 1 OF 1 THIRD ANGLE PROJECTION:; ± 0.020 ± 0.010 ± 0.005 ± 0.0005 ± 0.5 DEG; REVISION HISTORY; ZONE; DESCRIPTION; DATE; APPROVED; INITIAL RELEASE; hhmi\\arnoldj; P.159 THRU

ALTERED ITEM NOTES:
1. THIS IS A PART MANUFACTURED BY ANOTHER VENDOR (DETAILS BELOW). THE DIMENSIONS SHOWN IN THIS DRAWING
ARE REQUIRED MODIFICATIONS.
2. ALL REFERENCE/INSPECTION DIMENSIONS SHALL BE VERIFIED PRIOR TO ALTERATIONS.
3. ALTERED ITEM VENDOR: MCMASTER- CARR
4. ALTERED ITEM PART NUMBER: 92558A100
5. ALTERED ITEM DESCRIPTION: THUMBSCREW, M4

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

MBS POS-T-SCREW BASE.ipt

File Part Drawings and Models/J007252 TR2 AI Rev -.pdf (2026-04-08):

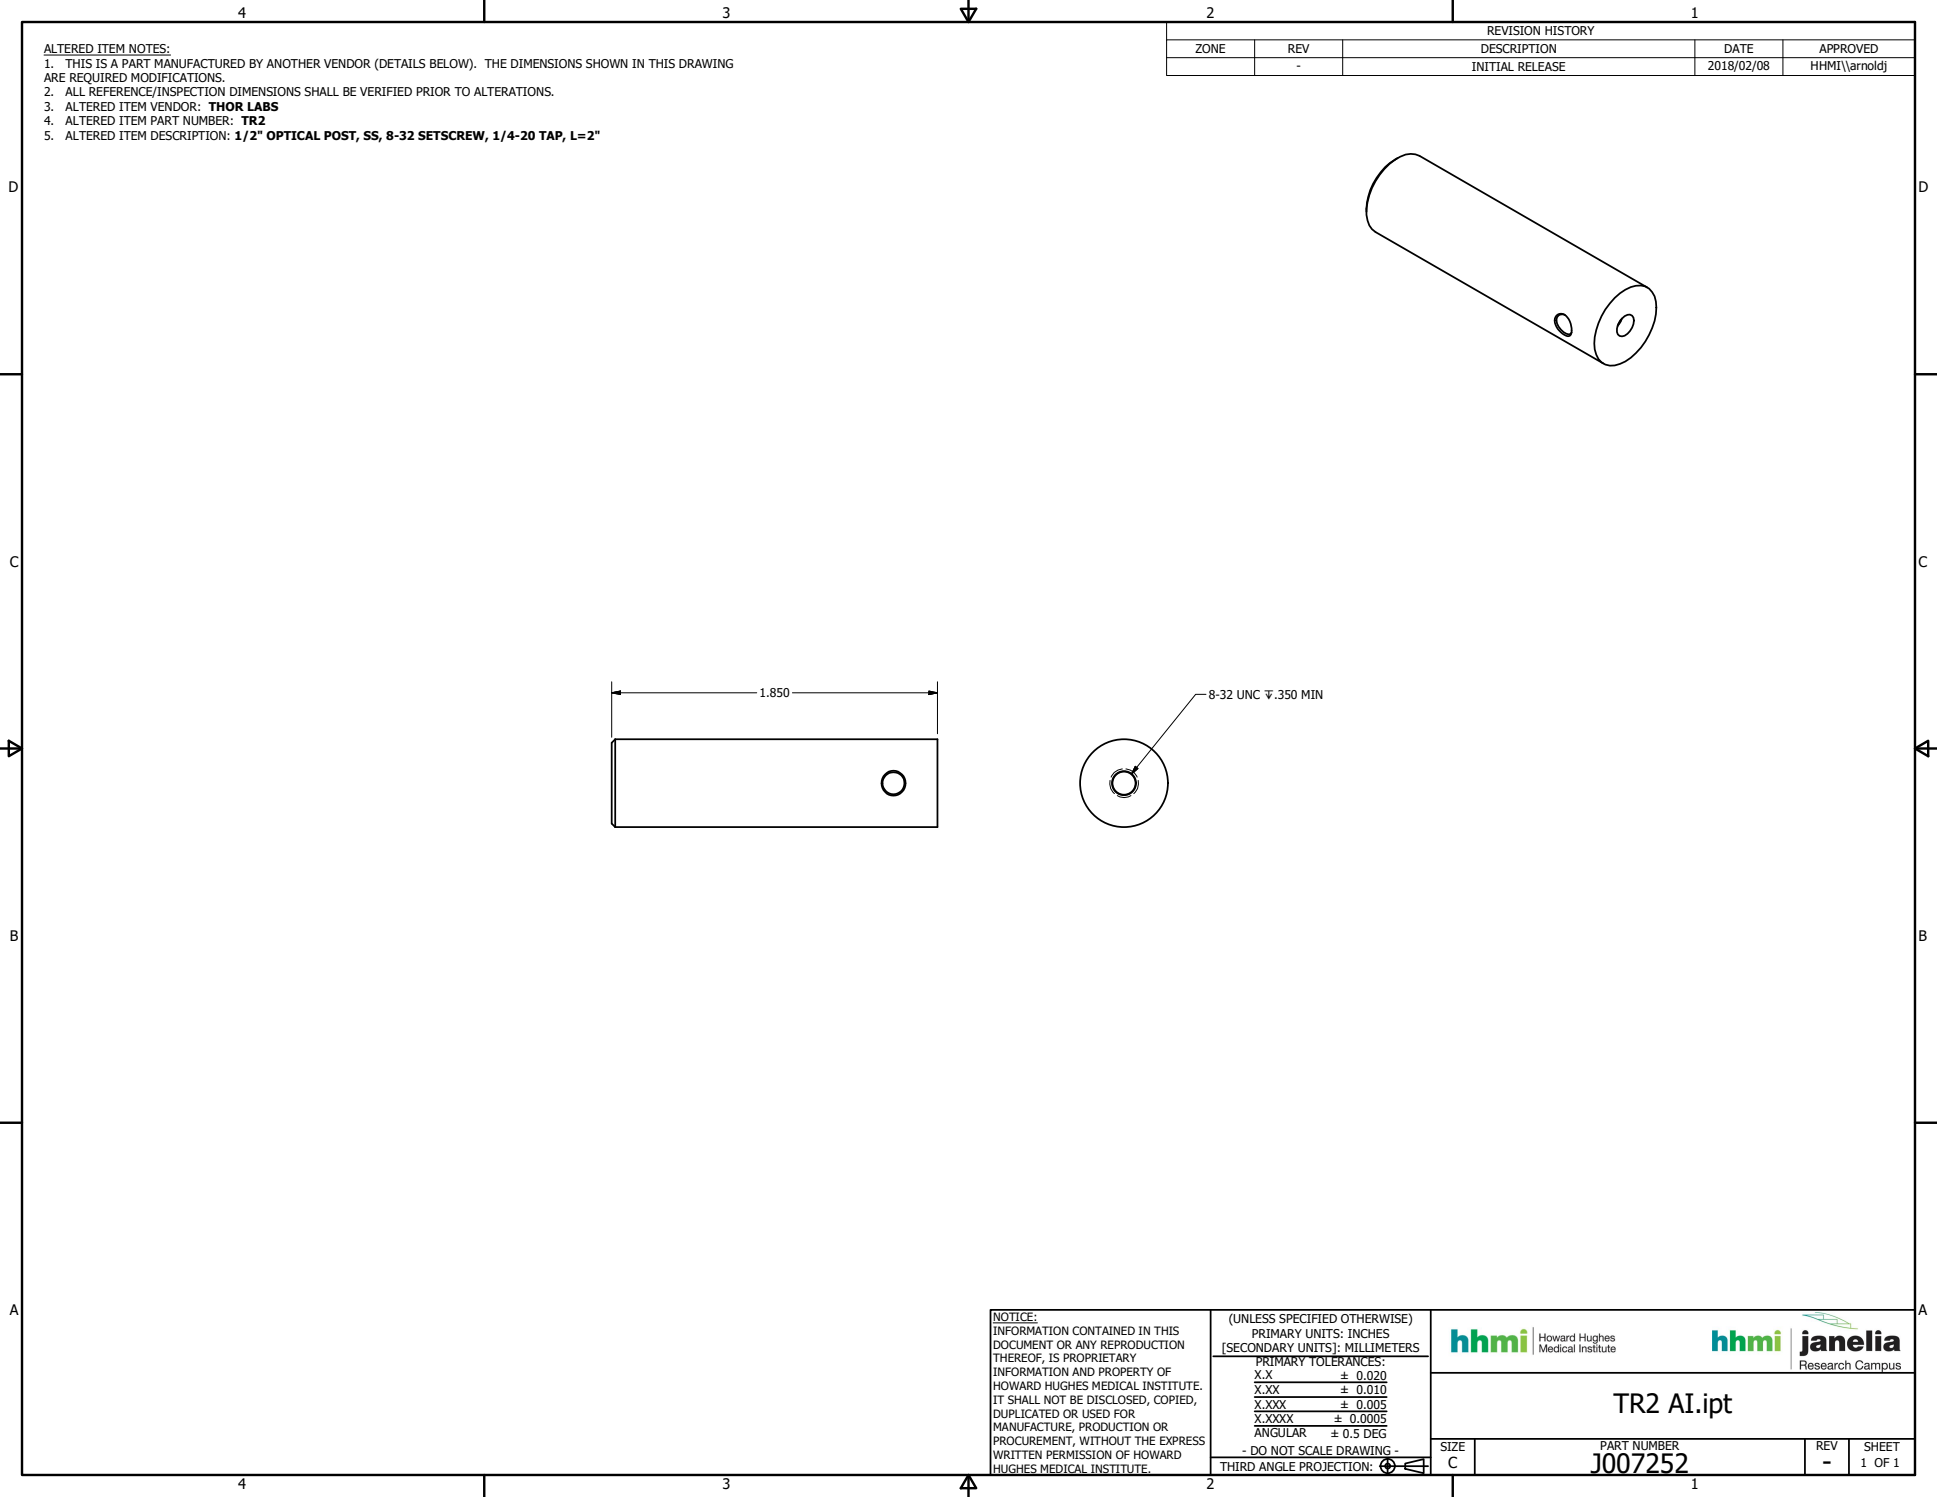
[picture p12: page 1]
PART NUMBER; 1 OF 1 THIRD ANGLE PROJECTION:; ± 0.020 ± 0.010 ± 0.005 ± 0.0005 ± 0.5 DEG; TR2 AI.ipt; REVISION HISTORY

ALTERED ITEM NOTES:
1. THIS IS A PART MANUFACTURED BY ANOTHER VENDOR (DETAILS BELOW). THE DIMENSIONS SHOWN IN THIS DRAWING
ARE REQUIRED MODIFICATIONS.
2. ALL REFERENCE/INSPECTION DIMENSIONS SHALL BE VERIFIED PRIOR TO ALTERATIONS.
3. ALTERED ITEM VENDOR: THOR LABS
4. ALTERED ITEM PART NUMBER: TR2
5. ALTERED ITEM DESCRIPTION: 1/2" OPTICAL POST, SS, 8-32 SETSCREW, 1/4-20 TAP, L=2"

ZONE | REV | DESCRIPTION | DATE | APPROVED

- | INITIAL RELEASE | 2018/02/08 | HHMI\\arnoldj

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
